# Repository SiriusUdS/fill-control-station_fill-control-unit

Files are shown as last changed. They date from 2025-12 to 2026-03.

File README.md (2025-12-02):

# template
Template repository. Repository name format: &lt;stm[model]|py|desktop>-&lt;project_name>-&lt;layer>  

Example:
- stmf411-engine-hal
- stm-engine-components

For the README.md file, it should be structured like the following:

---

# Project Name

> One-sentence summary describing what your project does or solves.

---

## Table of Contents
- [About](#about)
- [Project Structure](#project-structure)
- [Requirements](#requirements)
- [Installation / Build](#installation--build)
- [Usage](#usage)
- [Configuration](#configuration)
- [Troubleshooting](#troubleshooting)

---

## About

Explain what the project is, what problem it solves, and any relevant context.

Example:  
> This project implements the HAL layer of the engine project on the STMF411...

---

## Project Structure
project-root/  
│  
├── src/ # Source files  
├── include/ # Header files  
├── scripts/ # Utility scripts or build helpers  
├── config/ # Configuration or calibration files  
├── docs/ # Documentation and manuals  
├── tests/ # Unit or integration tests  
└── README.md  

---

## Requirements

List any hardware, software, or library dependencies needed to build or run the project.

Example:

- **Hardware:** STM32F4 Series, Raspberry Pi 4  
- **Compiler:** GCC 13+ or ARM-GCC toolchain  
- **Libraries:**  
  - HAL Drivers (for STM32)  
  - WiringPi (for Raspberry Pi)  
  - CMake ≥ 3.20  

---

## Installation / Build

List of steps required to install and build the project.

Example:

- Clone the project
- Download Visual Studio 2022 from this [Link](#www.duckduckgo.com)
- Open the sln file with Visual Studio
- Run the build

## Usage

List of steps required to run and/or debug the project.

Example:
- Open the project with Visual Studio 2022
- Press the `start` button

## Configuration

List of configuration files if any

Example:
- vcpkg.json
- .clang-tidy
- .clang-format

## Troubleshooting

QA kind of section with the most common problems and how to fix them

> The application build fails after the installation

Make sure that the vcpkg modules have been downloaded. Check the `use manifest` option in Visual Studio to see if the modules are downloaded automatically or not

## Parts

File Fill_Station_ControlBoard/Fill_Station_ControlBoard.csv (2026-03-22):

Id | Designator | Footprint | Quantity | Designation | Supplier and ref
1 | C52,C49,C13,C85,C60,C58,C56,C15,C6,C87,C69,C32,C101,C74,C65,C2,C100 | C_0603_1608Metric | 17 | 10u
2 | R12,R98,R97,R94,R43,R96,R95,R45,R46,R48,R44,R47,R4,R134,R132,R8,R9,R133 | R_0402_1005Metric | 18 | 10k
3 | Q3,Q2,Q1 | SOT-23 | 3 | AO3400A
4 | C78,C61,C75 | C_0603_1608Metric | 3 | 22u
5 | C71,C55,C5 | C_0805_2012Metric | 3 | 10u
6 | C4,C3,C84 | C_1210_3225Metric | 3 | 22u
7 | C59 | CP_Elec_5x5.3 | 1 | 10uF_50V
8 | C57 | CP_Elec_6.3x7.7 | 1 | 100uF_50V
9 | D15 | D_SOD-123 | 1 | 6.4V
10 | F2 | Fuse_1206_3216Metric | 1 | Polyfuse
11 | R68,R78,R67 | R_0603_1608Metric | 3 | R_US
12 | R99,R91,R38,R113,R101,R104,R100,R40,R39,R88,R116,R115,R41,R42,R89,R103,R114,R62,R92,R90,R93 | R_0402_1005Metric | 21 | 22
13 | J2 | TerminalBlock_Phoenix_PT-1,5-2-5.0-H_1x02_P5.00mm_Horizontal | 1 | Ematch1
14 | C116,C86,C117,C115,C14,C38,C63,C20,C1,C12 | C_0603_1608Metric | 10 | 100n
15 | D9,D12,D4,D7,D11,D8,D13,D14,D5,D10 | LED_0603_1608Metric | 10 | LED
16 | R32,R81,R30,R82,R29 | C_0603_1608Metric | 5 | 22
17 | C30,C41,C36,C48,C40,C37,C92,C28,C42,C94,C23,C25,C27,C31,C44,C91,C35,C46,C34,C39,C103,C90,C43,C33,C83,C16,C26,C98,C29 | C_0402_1005Metric | 29 | 100n
18 | R11,R77,R10 | R_0603_1608Metric | 3 | 1k
19 | C93,C105,C7,C89 | C_1210_3225Metric | 4 | 1000p - 2000V
20 | C73,C70 | C_0603_1608Metric | 2 | 100nF
21 | J19 | AMASS_XT60-M_1x02_P7.20mm_Vertical | 1 | ~
22 | J15 | USB_C_Receptacle_GCT_USB4105-xx-A_16P_TopMnt_Horizontal | 1 | USB_C_Receptacle_USB2.0_14P
23 | Y2 | Oscillator_SMD_Abracon_ASV-4Pin_7.0x5.1mm | 1 | ASV-32.768kHz
24 | C81,C72,C80,C107,C50,C62,C68,C22,C77,C45,C79,C9,C8,C47,C76,C112,C102,C97,C53 | C_0603_1608Metric | 19 | 1u
25 | C66 | C_0603_1608Metric | 1 | 10n
26 | R53,R52,R111 | C_0402_1005Metric | 3 | 10k
27 | R56,R55,R73,R86 | R_0603_1608Metric_Pad0.98x0.95mm_HandSolder | 4 | 0
28 | R34,R25 | R_0603_1608Metric_Pad0.98x0.95mm_HandSolder | 2 | 22
29 | D16 | D_SMA | 1 | SMAJ20A
30 | C95 | C_0402_1005Metric | 1 | 10u
31 | R3,R162,R2 | R_0603_1608Metric | 3 | 50m
32 | R50,R49,R28,R51,R35,R84,R26,R37,R117,R1,R87,R120,R119,R118 | R_0603_1608Metric_Pad0.98x0.95mm_HandSolder | 14 | 10k
33 | C11,C10 | CP_Elec_4x5.4 | 2 | 47uF
34 | R79,R80 | R_0603_1608Metric_Pad0.98x0.95mm_HandSolder | 2 | 5.1k
35 | R72,R71,R76,R33,R74,R31 | R_0603_1608Metric_Pad0.98x0.95mm_HandSolder | 6 | 680
36 | R65,R5 | C_0603_1608Metric | 2 | 365k
37 | R7,R75 | C_0603_1608Metric | 2 | 10k
38 | H2,H3,H4,H1 | MountingHole_3.2mm_With_Spacer_H10mm | 4 | M3_Hole_With_Spacer_H10mm
39 | C104,C99 | C_0402_1005Metric | 2 | 10n
40 | U10,U11,U12 | RDN0011A-MFG | 3 | TPSM33620-Q1
41 | J1 | RJ45_Wuerth_74980111211_Horizontal | 1 | RJ45_Wuerth_74980111211
42 | R54,R112 | C_0402_1005Metric | 2 | 0
43 | L4 | C_0402_1005Metric | 1 | L_Ferrite
44 | R64,R69,R70 | R_0603_1608Metric_Pad0.98x0.95mm_HandSolder | 3 | 1.5k
45 | J16 | DSUB-9_Socket_Vertical_P2.77x2.84mm_MountingHoles | 1 | DE9_Socket_MountingHoles
46 | Y1,Y4 | Oscillator_SMD_Abracon_ASV-4Pin_7.0x5.1mm | 2 | ASV-25.000MHz
47 | U2 | LQFP-176_24x24mm_P0.5mm | 1 | STM32H747IITx
48 | J12 | PinSocket_2x05_P2.00mm_Vertical | 1 | Conn_02x05_Counter_Clockwise
49 | J7,J8,J11 | TerminalBlock_Phoenix_PT-1,5-2-5.0-H_1x02_P5.00mm_Horizontal | 3 | Screw_Terminal_2_P5.00mm
50 | D1,D2,D3 | SOT-23 | 3 | BAV99
51 | BZ1 | Buzzer_Murata_PKMCS0909E | 1 | Buzzer_TDK_PS1240
52 | IC1 | WSON-8-1EP_2x2mm_P0.5mm_EP0.9x1.6mm_ThermalVias | 1 | TPS259573DSGR
53 | U9,U6 | SOT-583-8 | 2 | TPS2116DRL
54 | U1 | Texas_RGV0016A_VQFN-16-1EP_4x4mm_P0.65mm_EP2.1x2.1mm | 1 | INA3221
55 | J14,J10 | microSD_HC_Hirose_DM3AT-SF-PEJM5 | 2 | Micro_SD_Card_Det_Hirose_DM3AT
56 | C51,C96 | C_0402_1005Metric | 2 | *
57 | R27,R36 | R_0603_1608Metric_Pad0.98x0.95mm_HandSolder | 2 | 50k
58 | R66 | C_0603_1608Metric | 1 | 100k
59 | L2 | R_0402_1005Metric | 1 | L_Ferrite
60 | SW2 | SW_DPDT_CK_JS202011JCQN | 1 | BOOT
61 | U8 | SOIC-20W_7.5x12.8mm_P1.27mm | 1 | ISOW1044
62 | R107 | R_0603_1608Metric_Pad0.98x0.95mm_HandSolder | 1 | 270
63 | R6 | R_0603_1608Metric | 1 | 100k
64 | C88 | C_0603_1608Metric | 1 | 100u
65 | F1 | Fuse_0603_1608Metric | 1 | 4A
66 | J9 | TerminalBlock_Phoenix_PT-1,5-6-3.5-H_1x06_P3.50mm_Horizontal | 1 | Screw_Terminal_6_P3.50mm
67 | J6 | TerminalBlock_Phoenix_PT-1,5-2-5.0-H_1x02_P5.00mm_Horizontal | 1 | Ematch2
68 | R63 | C_0603_1608Metric | 1 | 4.7k
69 | BT1 | Battery_Panasonic_CR2032-HFN_Horizontal_CircularHoles | 1 | RTC_BAT
70 | SW1 | SW_DPDT_CK_JS202011JCQN | 1 | RESET
71 | R106 | R_0603_1608Metric_Pad0.98x0.95mm_HandSolder | 1 | 1M
72 | U7 | SOT-23-6 | 1 | USBLC6-2SC6
73 | C67 | C_0603_1608Metric | 1 | 10nF
74 | C64 | C_0603_1608Metric | 1 | 3.3n
75 | U5 | Texas_RMQ0024A_WQFN-24-1EP_3x3mm_P0.4mm_EP1.9x1.9mm | 1 | DP83825I
76 | CR2 | SOT323-3L_STM | 1 | ESDCAN02-2BWY
77 | C54,C24 | C_0603_1608Metric | 2 | 4.7u
78 | C18,C19,C17,C21 | C_0603_1608Metric | 4 | 2.2u
79 | R85 | R_0603_1608Metric_Pad0.98x0.95mm_HandSolder | 1 | 120
80 | TP3,TP1,TP2,TP4 | TestPoint_Pad_D2.0mm | 4 | TestPoint
81 | J17,J18 | PinHeader_1x06_P2.54mm_Vertical | 2 | PINHD_1x6_Male
82 | R102 | R_0402_1005Metric | 1 | 6.49k

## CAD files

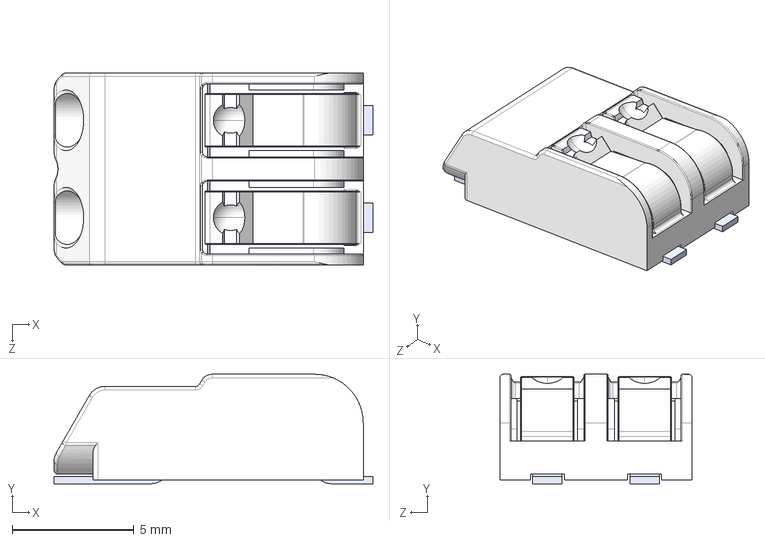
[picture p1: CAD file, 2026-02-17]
Fill_Station_ControlBoard/Librairies/3D/2060-452_998-404.STEP
13.1 x 4.50 x 7.90 mm

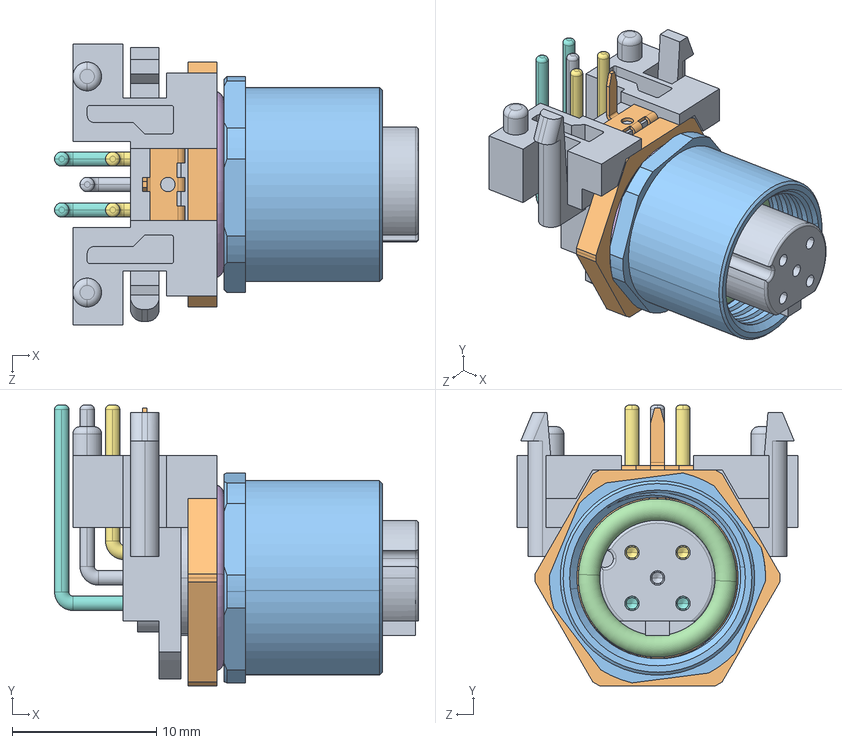
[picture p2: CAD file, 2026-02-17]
Fill_Station_ControlBoard/Librairies/3D/54-00386.STEP
25.3 x 19.5 x 19.5 mm

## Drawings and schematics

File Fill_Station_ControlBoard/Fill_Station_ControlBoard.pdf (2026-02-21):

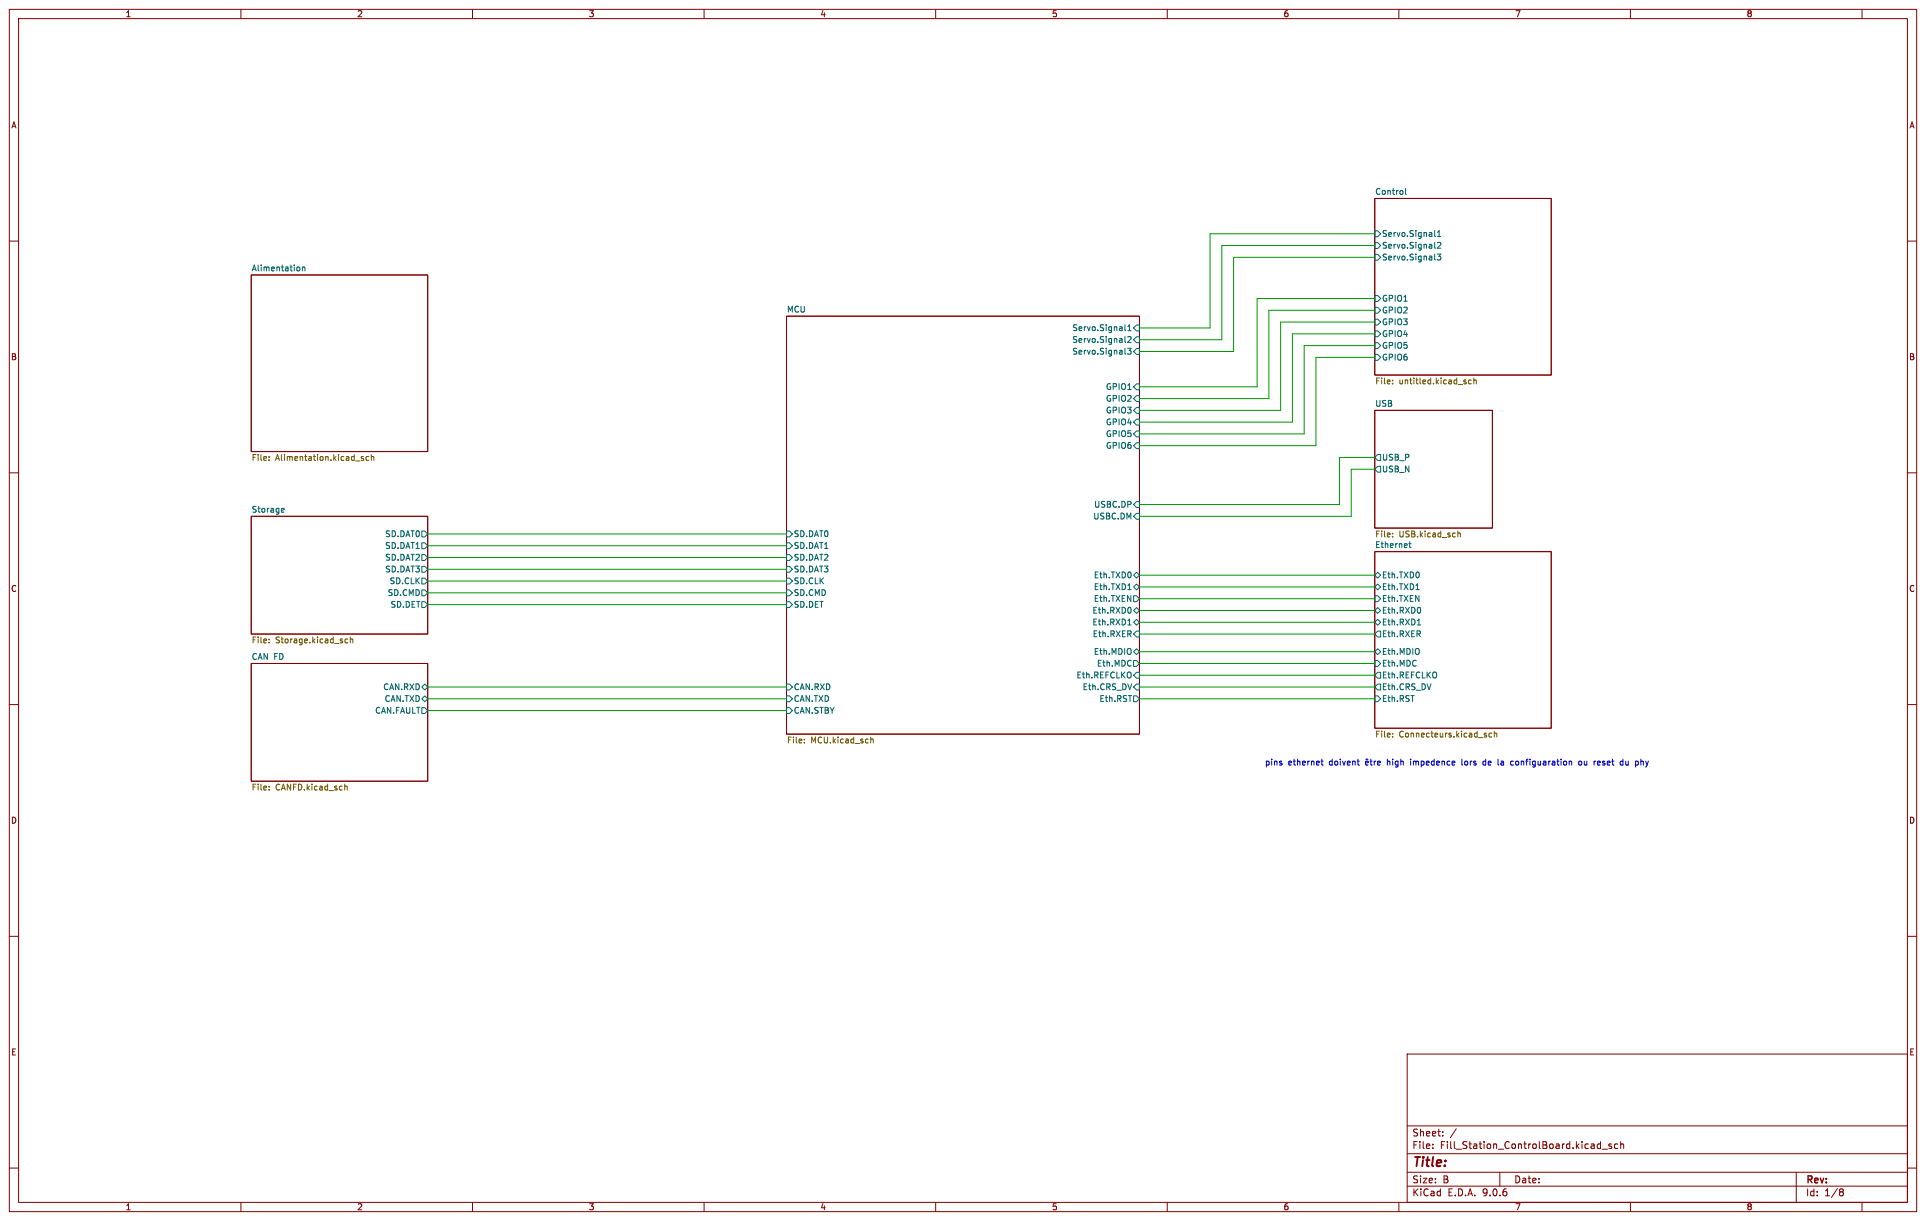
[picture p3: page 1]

Servo.Signal3 GPIO1 GPIO5 GPIO6 GPIO3 GPIO2 GPIO4 Control File: untitled.kicad_sch
File: USB.kicad_sch Servo.Signal1
Servo.Signal2

Servo.Signal1
Eth.TXD1 Eth.RXD1 Eth.RXD0 GPIO1 GPIO4 GPIO5 GPIO6 GPIO2 GPIO3 Servo.Signal2

USBC.DP CAN.TXD

SD.DAT2 SD.DAT0 SD.DAT1 SD.DAT3 SD.CLK

Eth.RST Eth.TXD0 Eth.MDIO

CAN.FAULT CAN FD

Eth.RST Eth.REFCLKO
Eth.CRS_DV

Id: 1/8 Title: File: Fill_Station_ControlBoard.kicad_sch Sheet: /

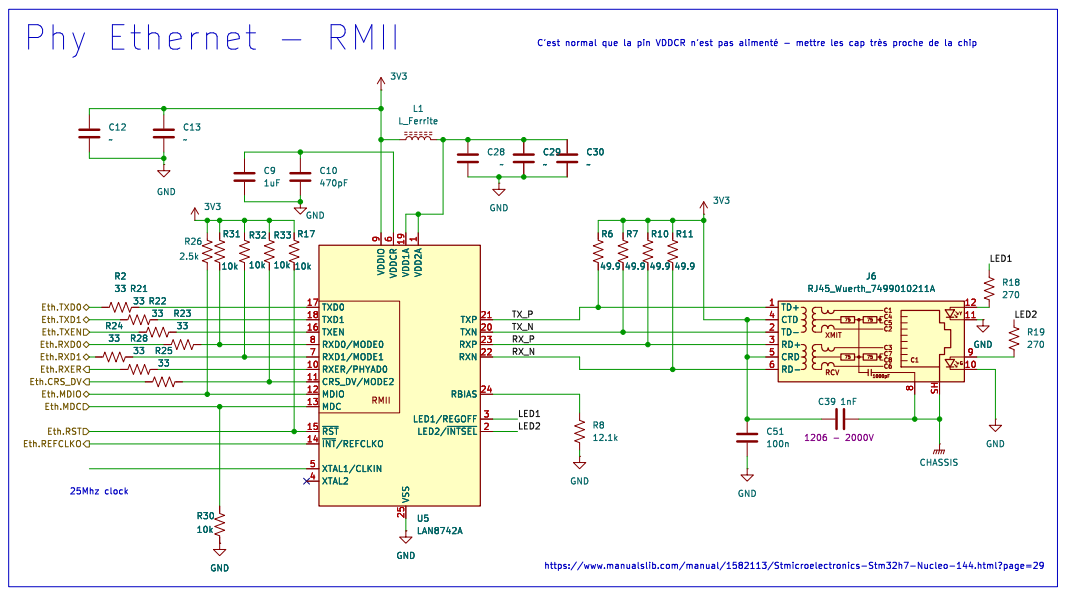
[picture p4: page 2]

1 TXP 21 TXN 20 RXP 23 RXN 22 RBIAS 24

Eth.TXD1 Eth.TXD0 Eth.RXD1 Eth.TXEN

Eth.CRS_DV
Eth.MDIO
Eth.RST Eth.MDC

Id: 2/8 Title: File: Connecteurs.kicad_sch Sheet: /Ethernet/

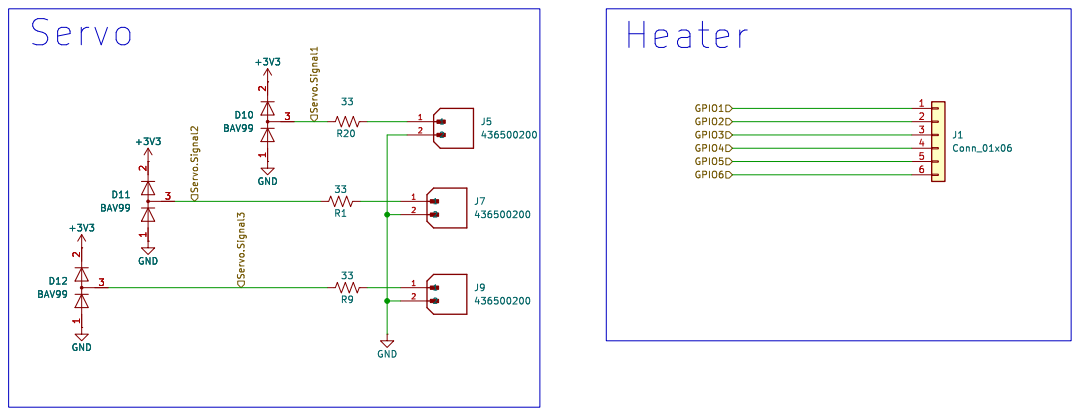
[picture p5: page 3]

Id: 3/8 Title: File: untitled.kicad_sch Sheet: /Control/ GND

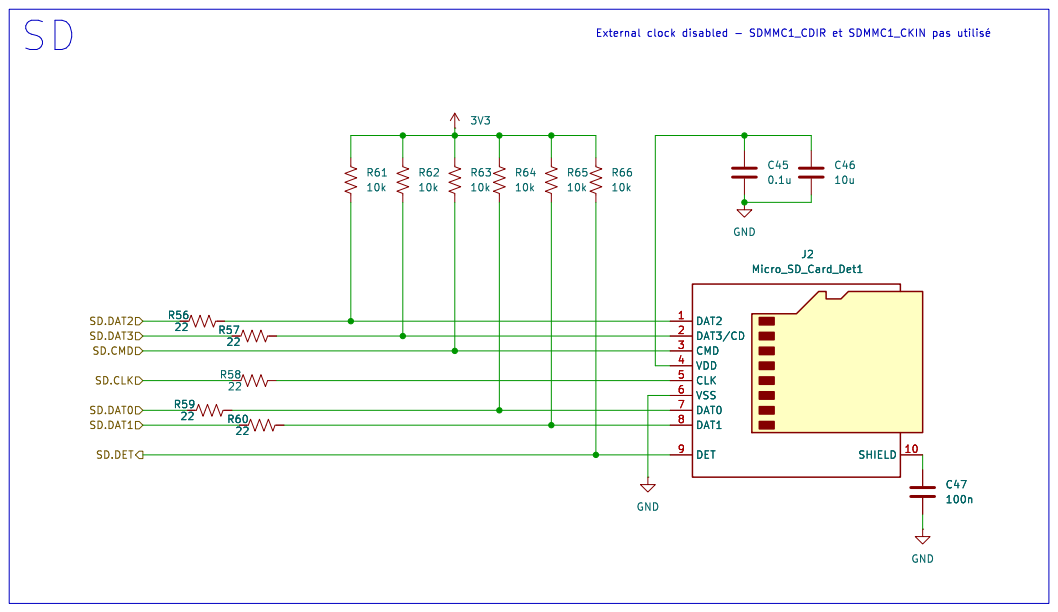
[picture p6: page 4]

0.1u SD.DET SD.CLK

SD.DAT0 SD.DAT1 SD.CMD

Id: 4/8 Title: File: Storage.kicad_sch Sheet: /Storage/

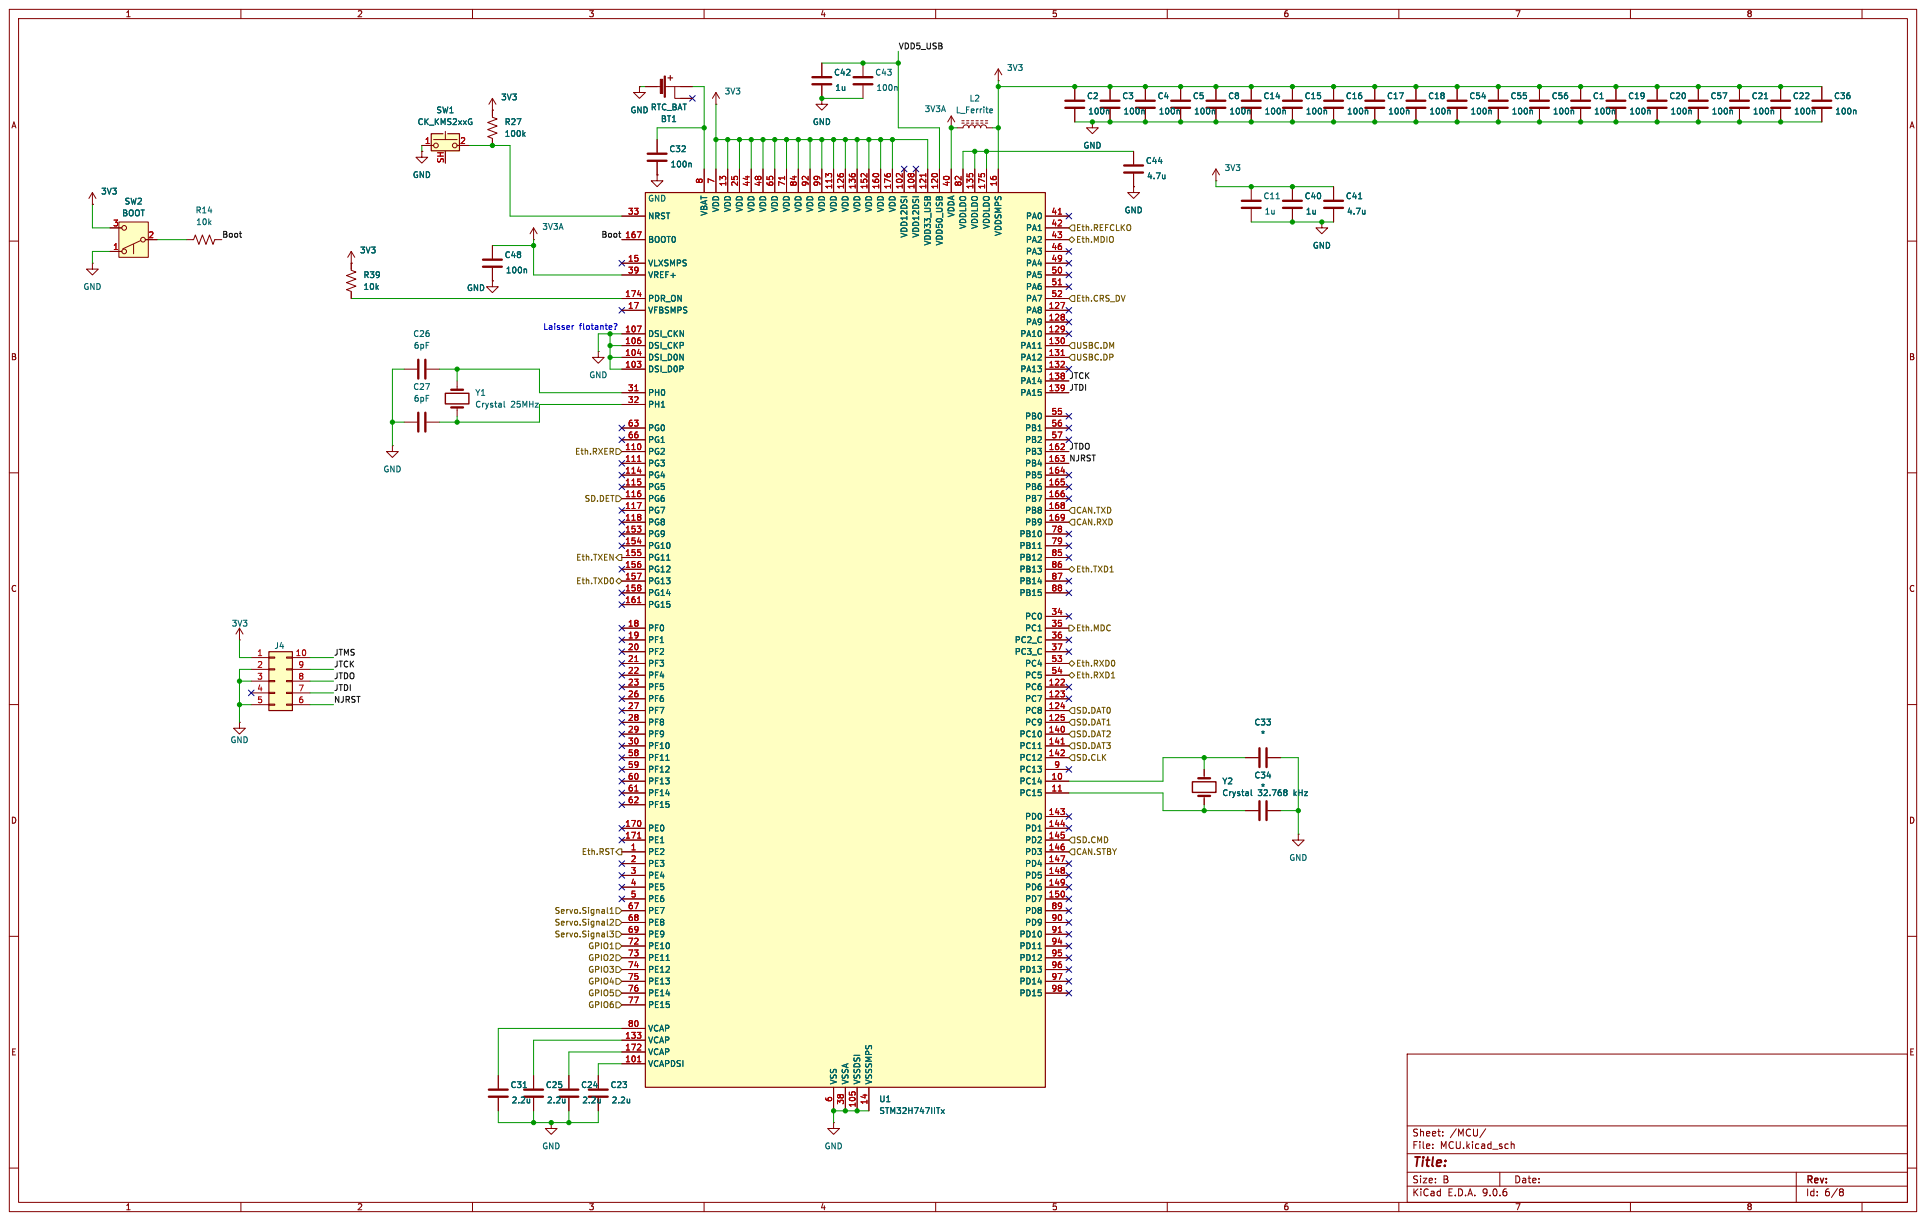
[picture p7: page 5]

SD.DAT3 SD.DAT0 SD.CLK

Id: 6/8 Title: File: MCU.kicad_sch Sheet: /MCU/

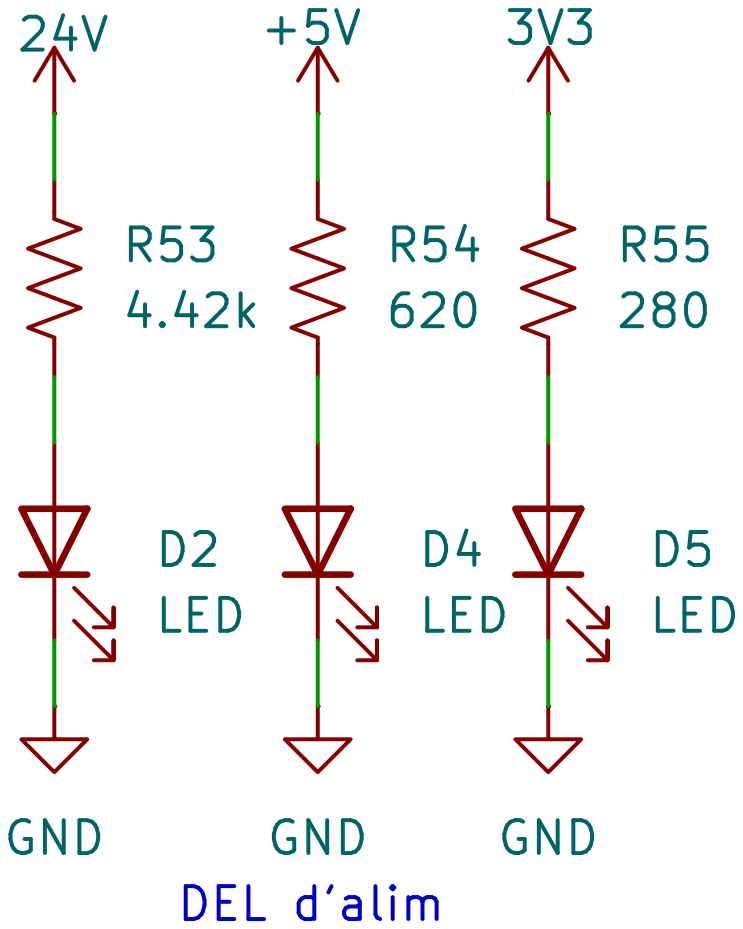
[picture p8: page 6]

Id: 7/8 Title: File: Alimentation.kicad_sch Sheet: /Alimentation/

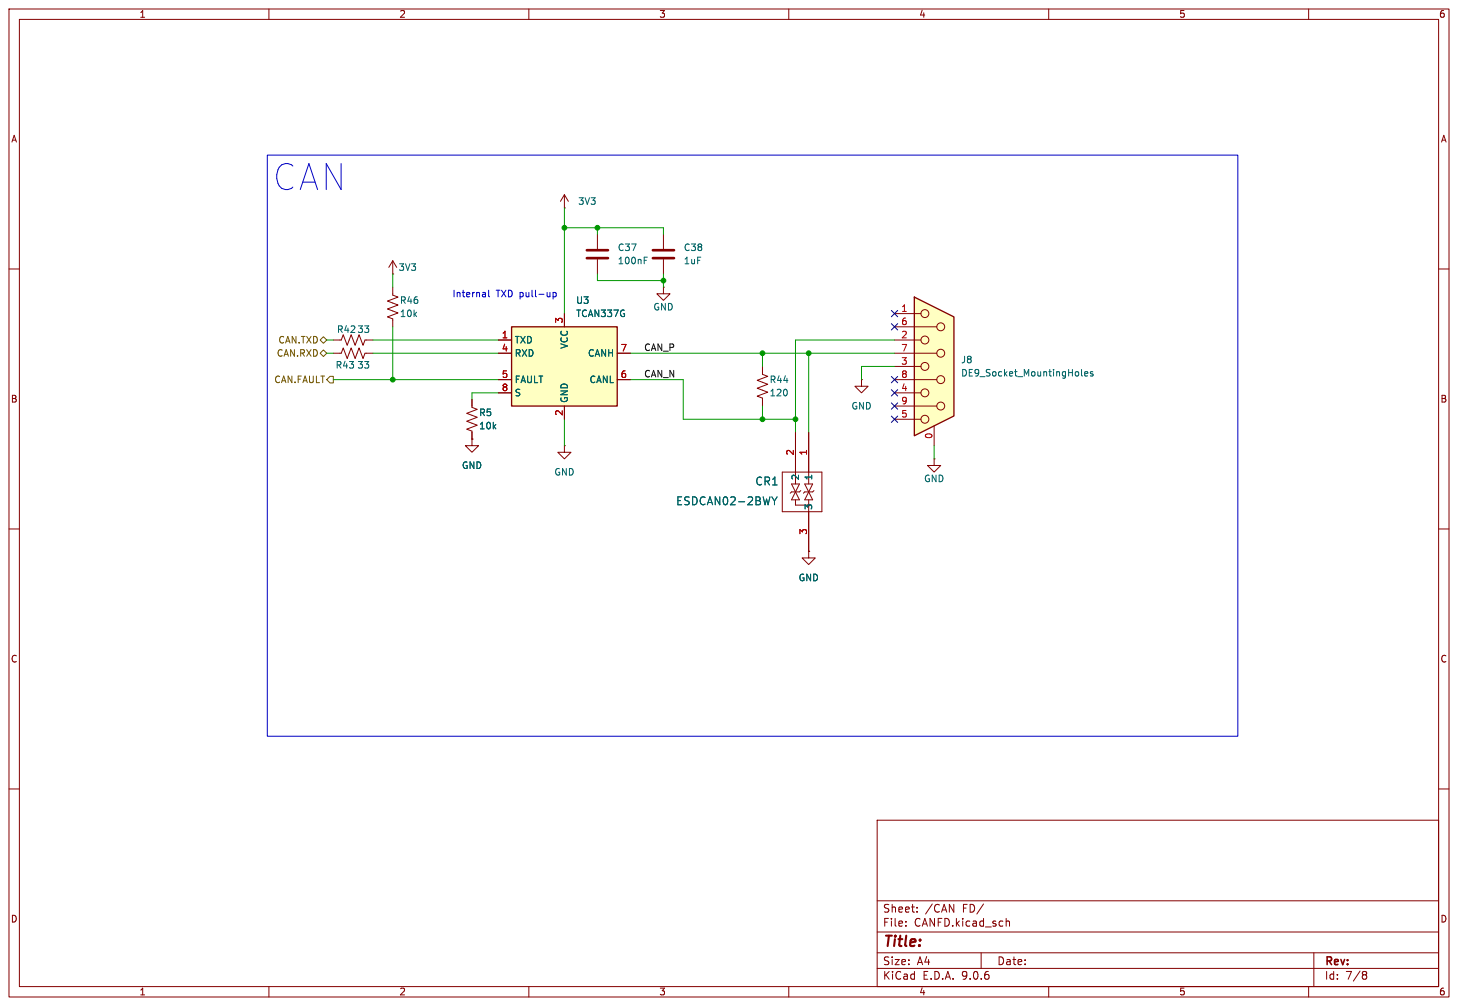
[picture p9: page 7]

2 CANH 7 CANL 6 U3 TCAN337G GND GND

CAN.FAULT CAN.TXD

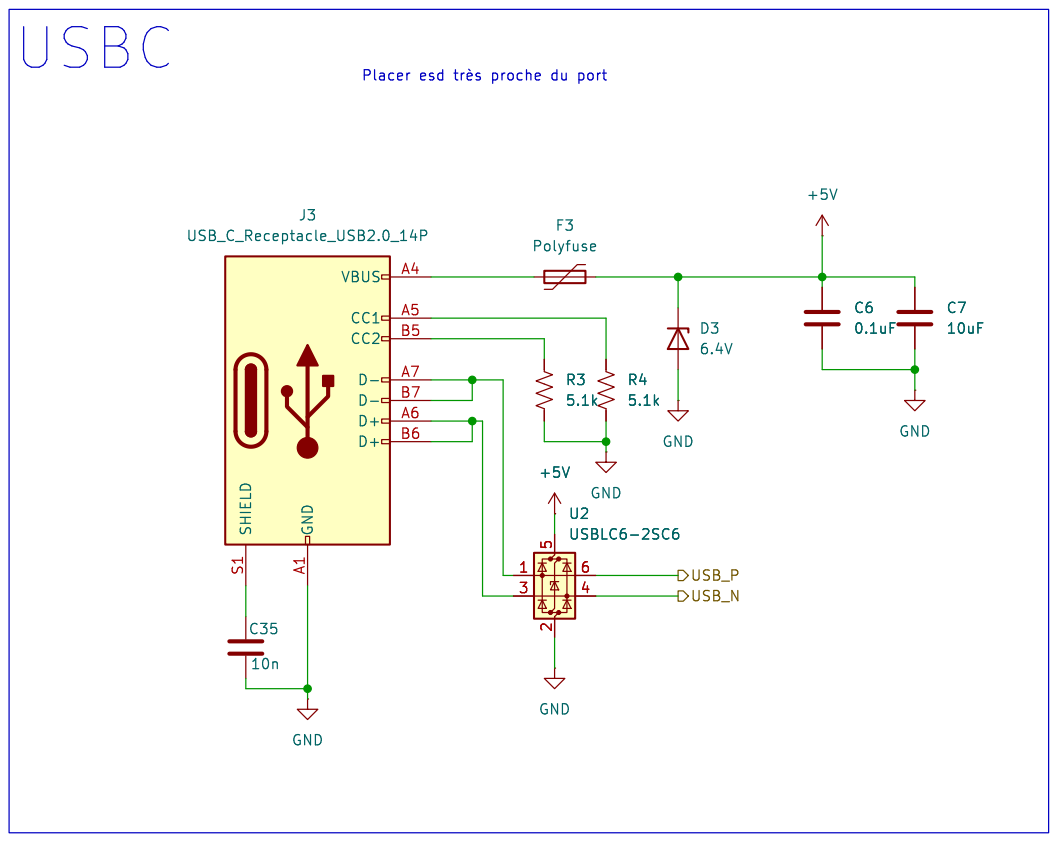
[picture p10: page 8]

Id: 8/8 Title: File: USB.kicad_sch Sheet: /USB/ C35

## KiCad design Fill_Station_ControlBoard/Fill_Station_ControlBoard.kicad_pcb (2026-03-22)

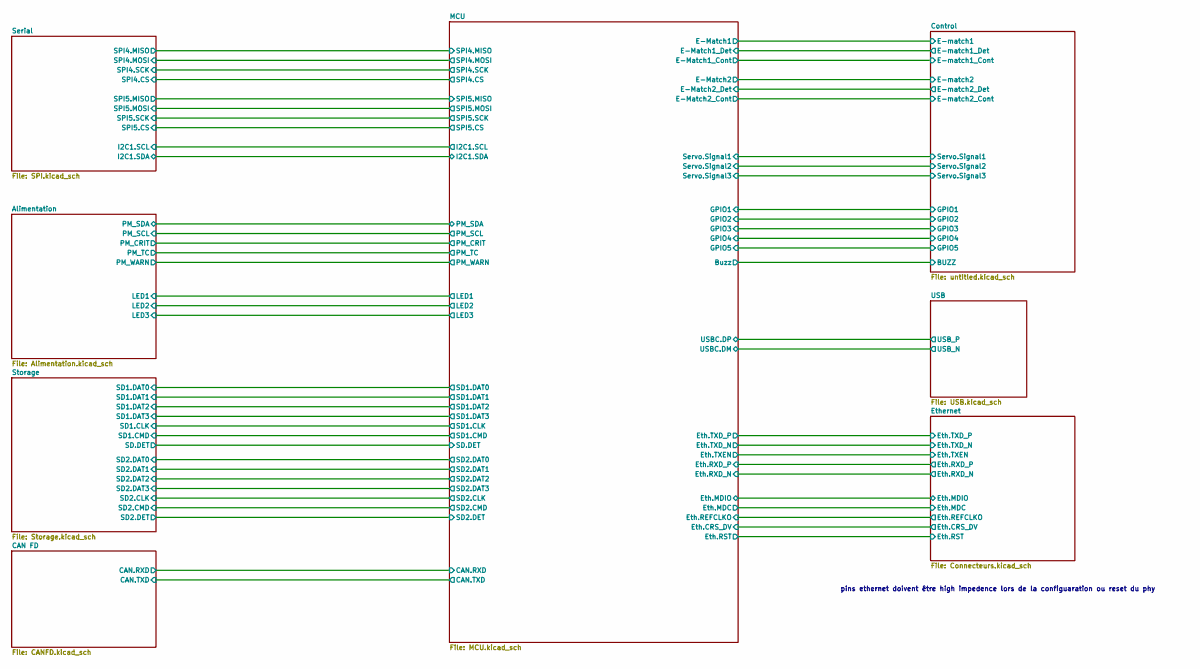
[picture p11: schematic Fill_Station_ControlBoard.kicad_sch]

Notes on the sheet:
pins ethernet doivent être high impedence lors de la configuaration ou reset du phy

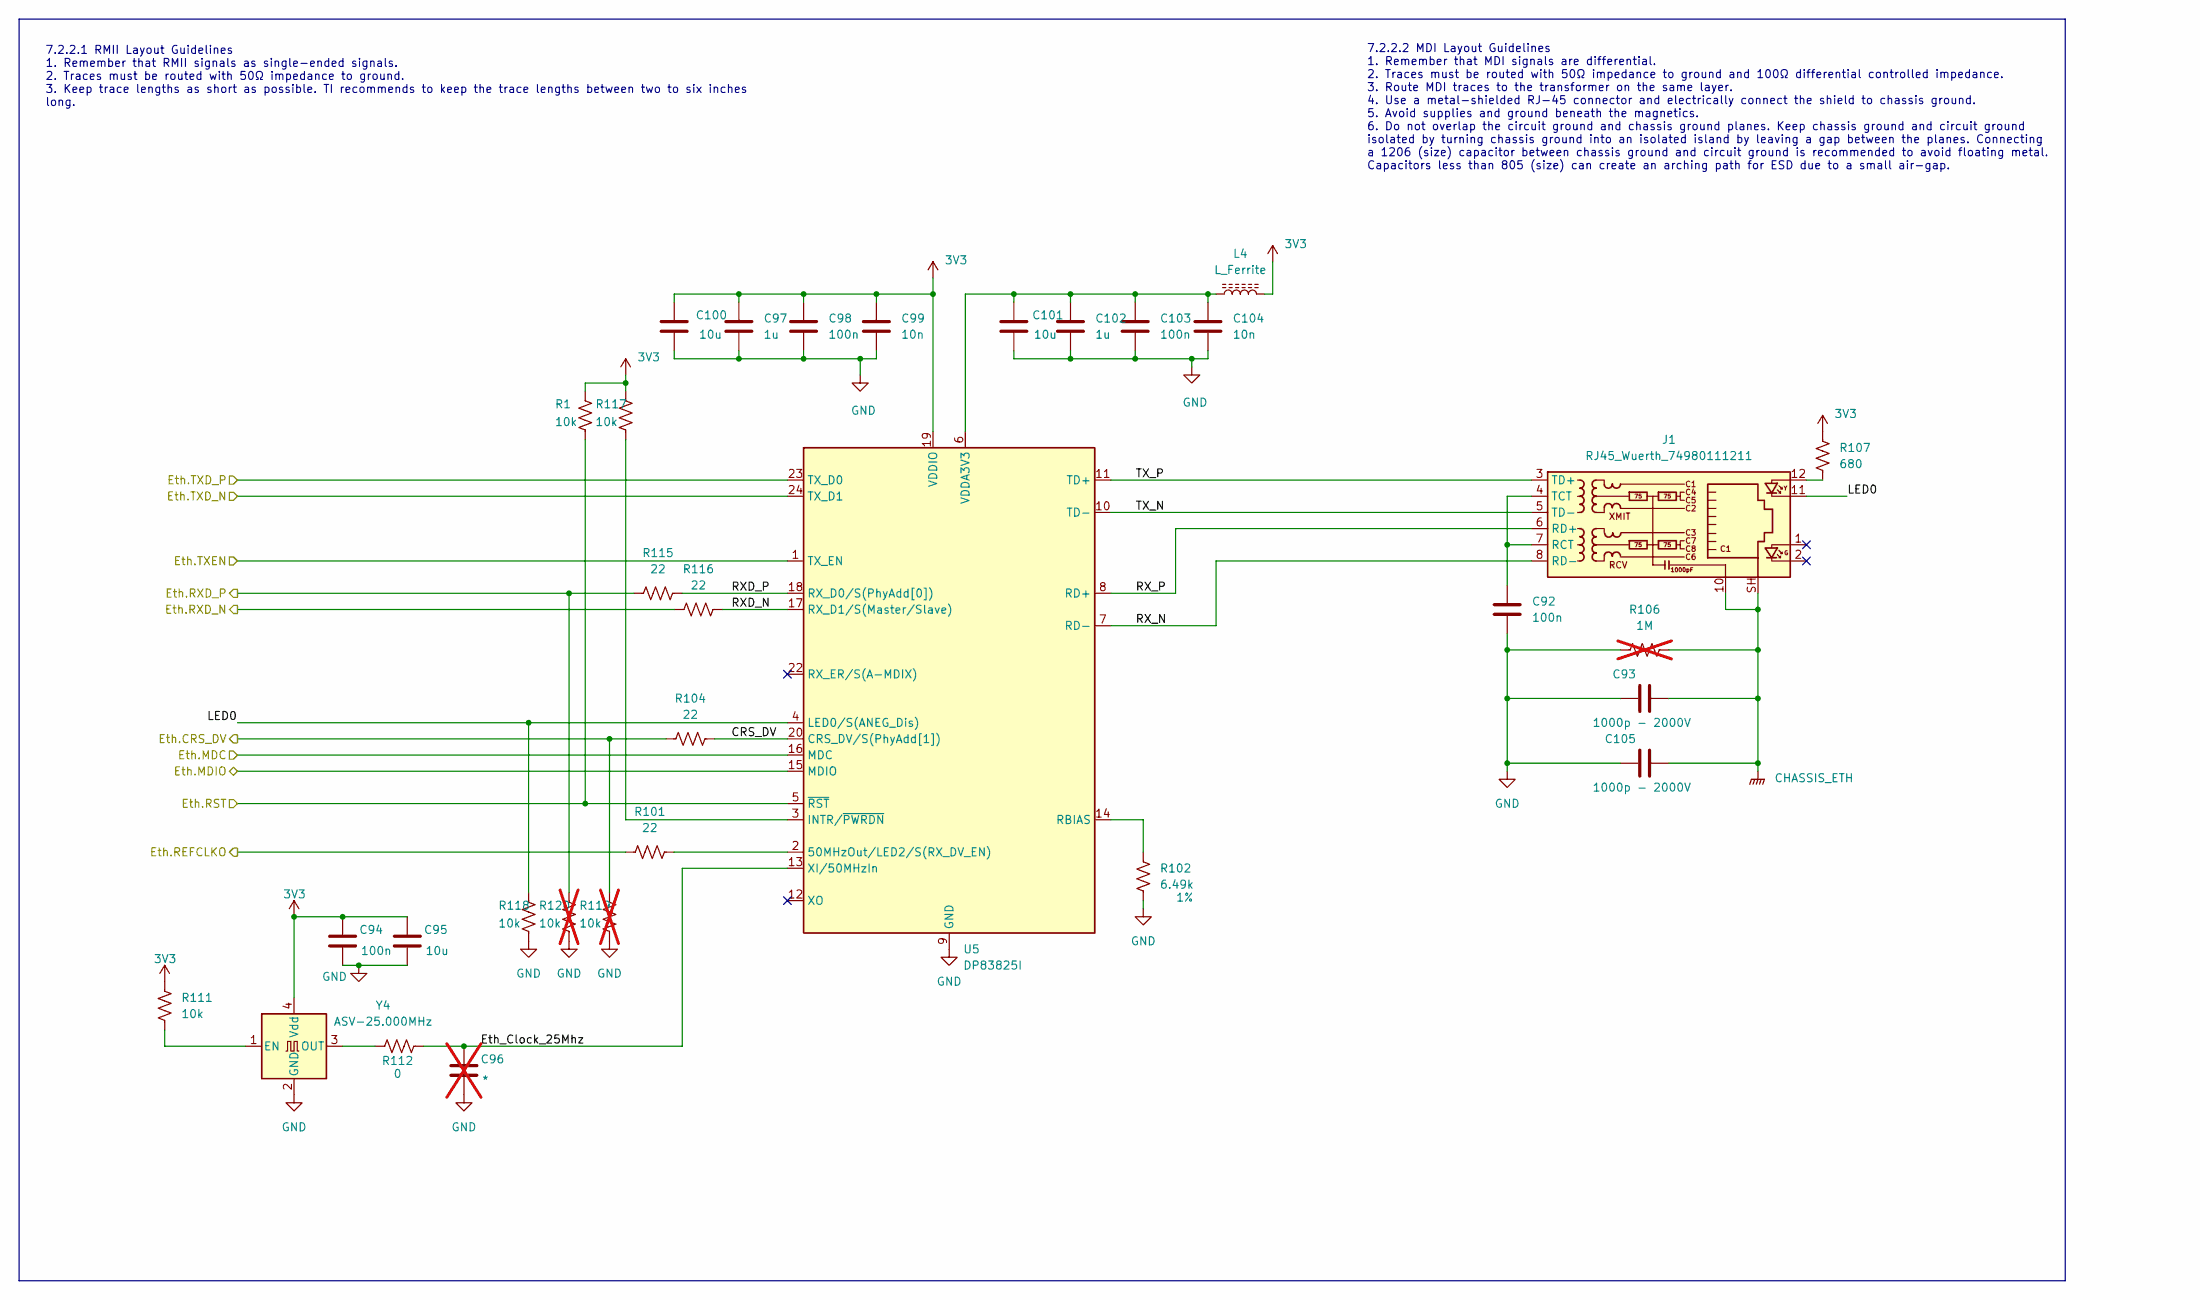
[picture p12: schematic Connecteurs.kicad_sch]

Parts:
C92, C94, C98, C103: 100n; C_0402_1005Metric; LCSC C60474
C93, C105: 1000p - 2000V; C_1210_3225Metric; LCSC C9196
C95, C100, C101: 10u; C_0603_1608Metric; LCSC C22399626
C96: *; C_0402_1005Metric; not fitted
C97, C102: 1u; C_0603_1608Metric; LCSC C59302
C99, C104: 10n; C_0402_1005Metric; LCSC C3850633
J1: RJ45_Wuerth_74980111211; RJ45_Wuerth_74980111211_Horizontal; LCSC C5523973
L4: L_Ferrite; R_0402_1005Metric; LCSC C160977
R1, R117, R118: 10k; R_0603_1608Metric; LCSC C22369937
R101, R104, R115, R116: 22; R_0402_1005Metric; LCSC C25092
R102: 6.49k; R_0402_1005Metric; LCSC C25916
R106: 1M; R_0603_1608Metric_Pad0.98x0.95mm_HandSolder; not fitted
R107: 680; R_0603_1608Metric_Pad0.98x0.95mm_HandSolder; LCSC C22356475
R111: 10k; R_0402_1005Metric; LCSC C173683
R112: 0; R_0402_1005Metric; LCSC C17168
R119, R120: 10k; R_0603_1608Metric; not fitted
U5: DP83825I; Texas_RMQ0024A_WQFN-24-1EP_3x3mm_P0.4mm_EP1.9x1.9mm; LCSC C783599
Y4: ASV-25.000MHz; Oscillator_SMD_Abracon_ASV-4Pin_7.0x5.1mm; LCSC C1987509

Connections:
3V3: C94.1, C95.1, C97.1, C98.1, C99.1, C100.1, L4.2, R1.1, R107.1, R111.1, R117.1, U5.19 (VDDIO), Y4.4 (Vdd); also elsewhere on the board
/Ethernet/CRS_DV: R104.2, U5.20 (CRS_DV/S(PhyAdd[1]))
/Ethernet/Eth.CRS_DV: R104.1, R119.1; also elsewhere on the board
/Ethernet/Eth.MDC: U5.16 (MDC); also elsewhere on the board
/Ethernet/Eth.MDIO: U5.15 (MDIO); also elsewhere on the board
/Ethernet/Eth.REFCLKO: R101.1; also elsewhere on the board
/Ethernet/Eth.RST: R1.2, U5.5 (~RST); also elsewhere on the board
/Ethernet/Eth.RXD_N: R116.1; also elsewhere on the board
/Ethernet/Eth.RXD_P: R115.1, R120.1; also elsewhere on the board
/Ethernet/Eth.TXD_N: U5.24 (TX_D1); also elsewhere on the board
/Ethernet/Eth.TXD_P: U5.23 (TX_D0); also elsewhere on the board
/Ethernet/Eth.TXEN: U5.1 (TX_EN); also elsewhere on the board
/Ethernet/Eth_Clock_25Mhz: C96.1, R112.2, U5.13 (XI/50MHzIn)
/Ethernet/LED0: J1.11, R118.1, U5.4 (LED0/S(ANEG_Dis))
/Ethernet/RXD_N: R116.2, U5.17 (RX_D1/S(Master/Slave))
/Ethernet/RXD_P: R115.2, U5.18 (RX_D0/S(PhyAdd[0]))
/Ethernet/RX_N: J1.8 (RD-), U5.7 (RD-)
/Ethernet/RX_P: J1.6 (RD+), U5.8 (RD+)
/Ethernet/TX_N: J1.5 (TD-), U5.10 (TD-)
/Ethernet/TX_P: J1.3 (TD+), U5.11 (TD+)
CHASSIS_ETH: C93.2, C105.2, J1.10, J1.SH, R106.2
GND: C92.2, C93.1, C94.2, C95.2, C96.2, C97.2, C98.2, C99.2, C100.2, C101.2, C102.2, C103.2, C104.2, C105.1, R102.2, R106.1, R118.2, R119.2, R120.2, U5.9 (GND), U5.21 (GND), U5.25 (GND), Y4.2 (GND); also elsewhere on the board
unnamed: J1.12, R107.2
unnamed: C92.1, J1.4 (TCT), J1.7 (RCT)
unnamed: R101.2, U5.2 (50MHzOut/LED2/S(RX_DV_EN))
unnamed: R117.2, U5.3 (INTR/~PWRDN)
unnamed: R102.1, U5.14 (RBIAS)
unnamed: C101.1, C102.1, C103.1, C104.1, L4.1, U5.6 (VDDA3V3)
unnamed: R111.2, Y4.1 (EN)
unnamed: R112.1, Y4.3 (OUT)

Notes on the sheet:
7.2.2.1 RMII Layout Guidelines 1. Remember that RMII signals as single-ended signals. 2. Traces must be routed with 50Ω impedance to ground. 3. Keep trace lengths as short as possible. TI recommends to keep the trace lengths between two to six inches long.
7.2.2.2 MDI Layout Guidelines 1. Remember that MDI signals are differential. 2. Traces must be routed with 50Ω impedance to ground and 100Ω differential controlled impedance. 3. Route MDI traces to the transformer on the same layer. 4. Use a metal-shielded RJ-45 connector and electrically connect t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

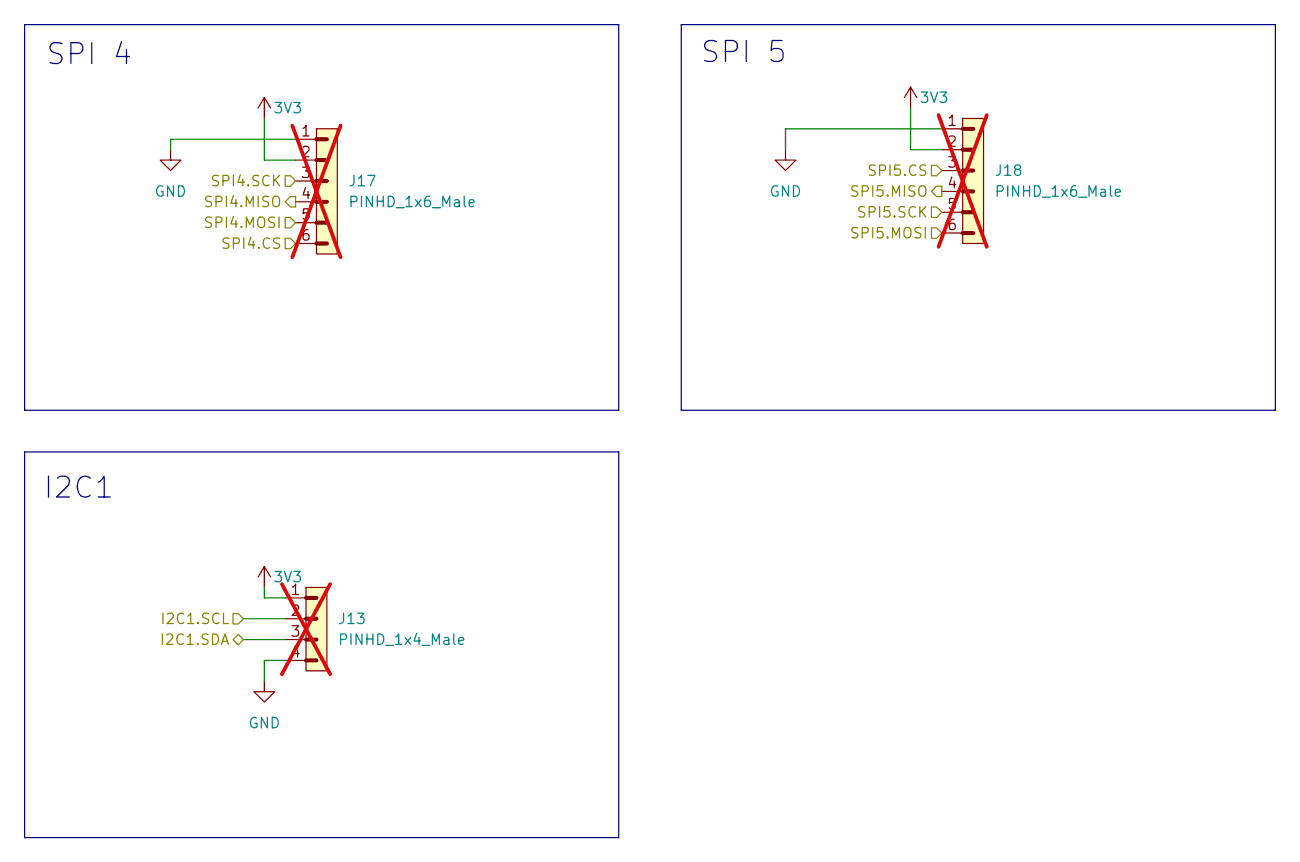
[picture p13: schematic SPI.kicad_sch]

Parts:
J13: PINHD_1x4_Male; PinHeader_1x04_P2.54mm_Vertical; not fitted
J17, J18: PINHD_1x6_Male; PinHeader_1x06_P2.54mm_Vertical; not fitted

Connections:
3V3: J13.1, J17.2, J18.2; also elsewhere on the board
/MCU/I2C1.SCL: J13.2; also elsewhere on the board
/MCU/I2C1.SDA: J13.3; also elsewhere on the board
/MCU/SPI4.CS: J17.6; also elsewhere on the board
/MCU/SPI4.MISO: J17.4; also elsewhere on the board
/MCU/SPI4.MOSI: J17.5; also elsewhere on the board
/MCU/SPI4.SCK: J17.3; also elsewhere on the board
/MCU/SPI5.CS: J18.3; also elsewhere on the board
/MCU/SPI5.MISO: J18.4; also elsewhere on the board
/MCU/SPI5.MOSI: J18.6; also elsewhere on the board
/MCU/SPI5.SCK: J18.5; also elsewhere on the board
GND: J13.4, J17.1, J18.1; also elsewhere on the board

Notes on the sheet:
SPI 5
SPI 4
I2C1

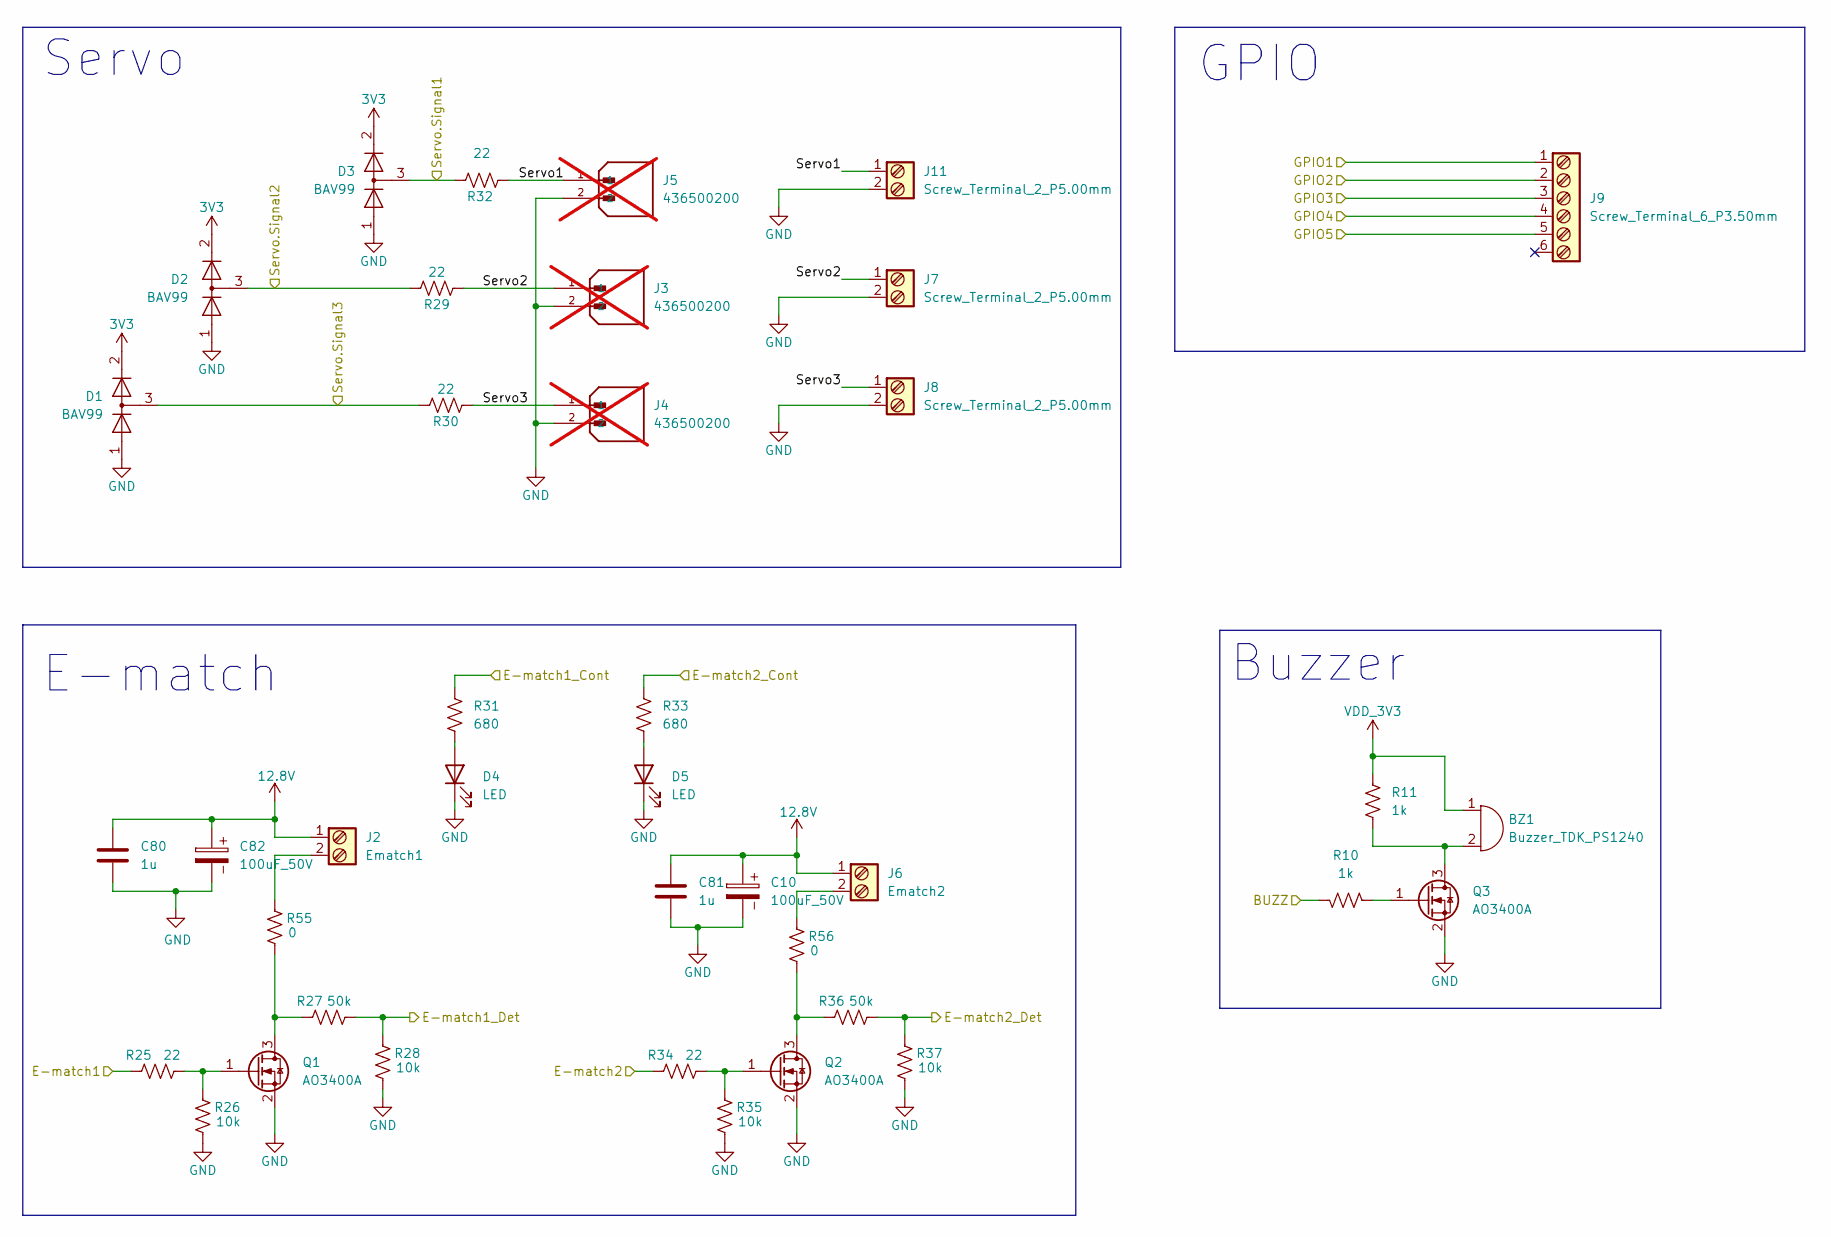
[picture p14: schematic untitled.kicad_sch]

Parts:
BZ1: Buzzer_TDK_PS1240; Buzzer_Murata_PKMCS0909E; Manufacturer Part Number PS1240P02BT; LCSC C910763
C10, C82: 100uF_50V; CP_Elec_6.3x7.7; LCSC C165974
C80, C81: 1u; C_0603_1608Metric; LCSC C59302
D1, D2, D3: BAV99; SOT-23; LCSC C68983
D4, D5: LED; LED_0603_1608Metric; LCSC C2286
J2: Ematch1; TerminalBlock_Phoenix_PT-1,5-2-5.0-H_1x02_P5.00mm_Horizontal
J3, J4, J5: 436500200; MOLEX_436500200; PARTREV D7; not fitted
J6: Ematch2; TerminalBlock_Phoenix_PT-1,5-2-5.0-H_1x02_P5.00mm_Horizontal
J7, J8, J11: Screw_Terminal_2_P5.00mm; TerminalBlock_Phoenix_PT-1,5-2-5.0-H_1x02_P5.00mm_Horizontal
J9: Screw_Terminal_6_P3.50mm; TerminalBlock_Phoenix_PT-1,5-6-3.5-H_1x06_P3.50mm_Horizontal
Q1, Q2, Q3: AO3400A; SOT-23; LCSC C20917
R10, R11: 1k; R_0603_1608Metric; LCSC C22356624
R25, R29, R30, R32, R34: 22; R_0402_1005Metric; LCSC C25092
R26, R28, R35, R37: 10k; R_0603_1608Metric; LCSC C22369937
R27, R36: 50k; R_0603_1608Metric_Pad0.98x0.95mm_HandSolder; LCSC C861451
R31, R33: 680; R_0603_1608Metric_Pad0.98x0.95mm_HandSolder; LCSC C22356475
R55, R56: 0; R_0402_1005Metric; LCSC C17168

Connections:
3V3: D1.2 (A), D2.2 (A), D3.2 (A); also elsewhere on the board
12.8V: C10.1, C80.1, C81.1, C82.1, J2.1, J6.1; also elsewhere on the board
/Control/BUZZ: R10.2; also elsewhere on the board
/Control/E-match1: R25.1; also elsewhere on the board
/Control/E-match1_Cont: R31.2; also elsewhere on the board
/Control/E-match1_Det: R27.2, R28.1; also elsewhere on the board
/Control/E-match2: R34.1; also elsewhere on the board
/Control/E-match2_Cont: R33.2; also elsewhere on the board
/Control/E-match2_Det: R36.2, R37.1; also elsewhere on the board
/Control/GPIO1: J9.1; also elsewhere on the board
/Control/GPIO2: J9.2; also elsewhere on the board
/Control/GPIO3: J9.3; also elsewhere on the board
/Control/GPIO4: J9.4; also elsewhere on the board
/Control/GPIO5: J9.5; also elsewhere on the board
/Control/Servo1: J5.1, J11.1, R32.2
/Control/Servo2: J3.1, J7.1, R29.1
/Control/Servo3: J4.1, J8.1, R30.1
/Control/Servo.Signal1: D3.3 (K), R32.1; also elsewhere on the board
/Control/Servo.Signal2: D2.3 (K), R29.2; also elsewhere on the board
/Control/Servo.Signal3: D1.3 (K), R30.2; also elsewhere on the board
GND: C10.2, C80.2, C81.2, C82.2, D1.1 (K), D2.1 (K), D3.1 (K), D4.1 (K), D5.1 (K), J3.2, J4.2, J5.2, J7.2, J8.2, J11.2, Q1.2 (S), Q2.2 (S), Q3.2 (S), R26.2, R28.2, R35.2, R37.2; also elsewhere on the board
unnamed: D4.2 (A), R31.1
unnamed: D5.2 (A), R33.1
unnamed: J2.2, R55.1
unnamed: J6.2, R56.1
unnamed: Q1.3 (D), R27.1, R55.2
unnamed: Q1.1 (G), R25.2, R26.1
unnamed: Q2.3 (D), R36.1, R56.2
unnamed: Q2.1 (G), R34.2, R35.1
unnamed: BZ1.2, Q3.3 (D), R11.2
unnamed: Q3.1 (G), R10.1
VDD_3V3: BZ1.1, R11.1

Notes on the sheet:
GPIO
E-match
Buzzer
Servo

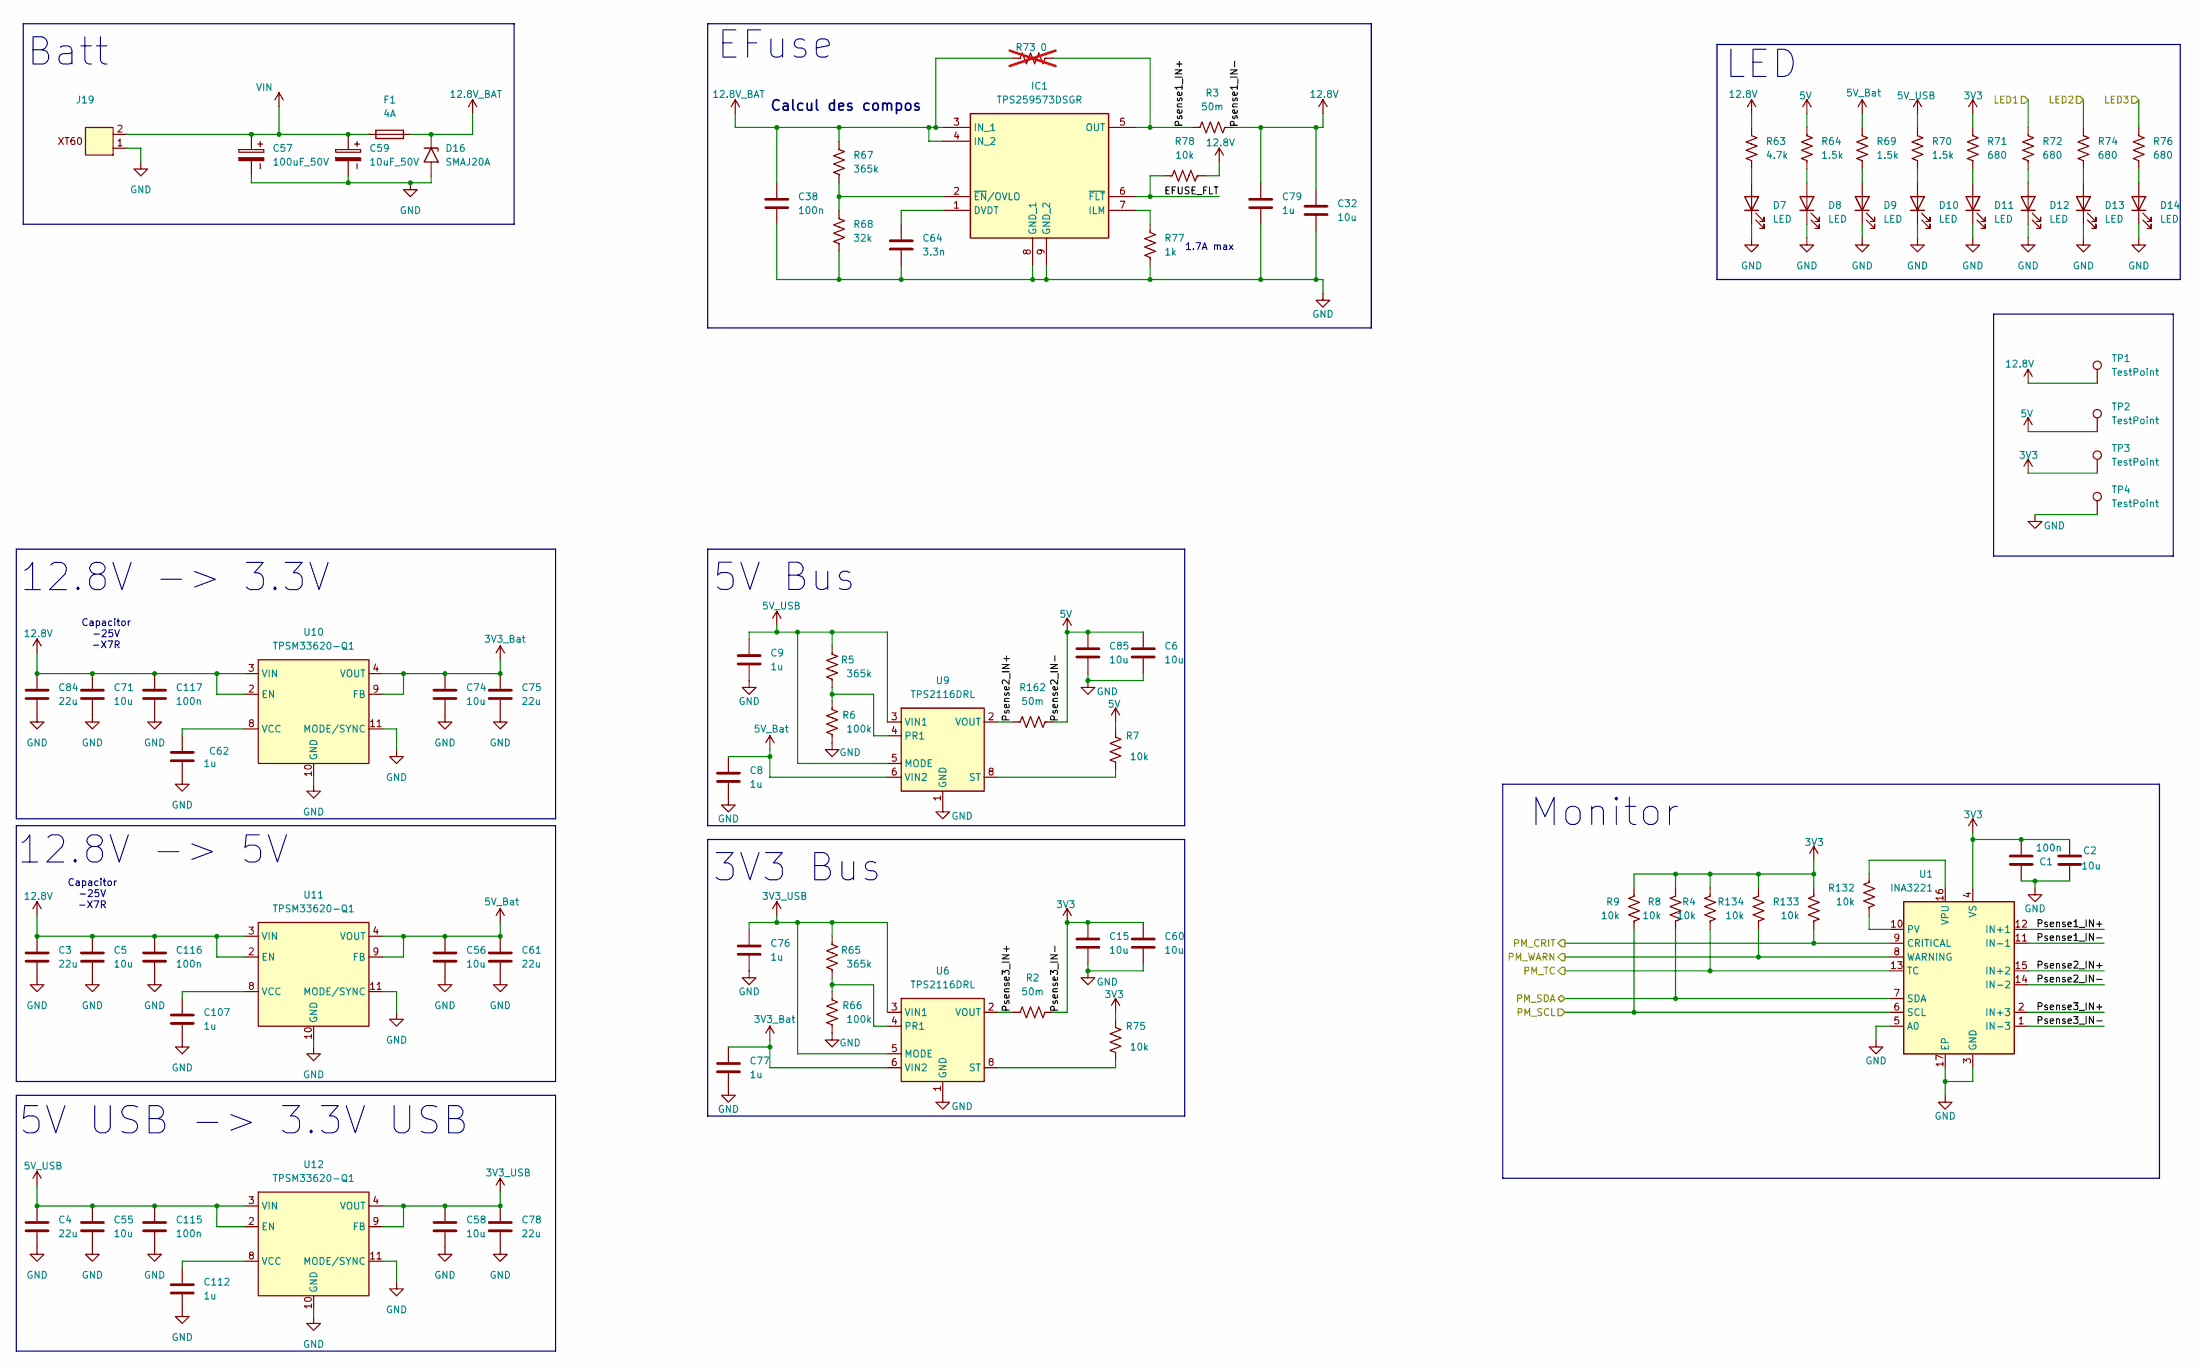
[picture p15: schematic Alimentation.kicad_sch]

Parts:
C1, C38, C115, C116, C117: 100n; C_0603_1608Metric; LCSC C14663
C2, C6, C15, C56, C58, C60, C74, C85: 10u; C_0603_1608Metric; LCSC C22399626
C3, C4: 22u; C_1210_3225Metric; LCSC C5341638
C5, C55, C71: 10u; C_0805_2012Metric; LCSC C326595
C8, C9, C62, C76, C77, C79, C107, C112: 1u; C_0603_1608Metric; LCSC C59302
C32: 10u; C_0603_1608Metric
C57: 100uF_50V; CP_Elec_6.3x7.7; LCSC C165974
C59: 10uF_50V; CP_Elec_5x5.3
C61, C75, C78: 22u; C_0603_1608Metric; LCSC C60077
C64: 3.3n; C_0603_1608Metric
C84: 22u; R_0603_1608Metric; LCSC C5341638
D7, D11, D12: LED; LED_0603_1608Metric; LCSC C12065
D8, D9, D10: LED; LED_0603_1608Metric; LCSC C2288
D13, D14: LED; LED_0603_1608Metric; LCSC C2286
D16: SMAJ20A; D_SMA; LCSC C10763
F1: 4A; Fuse_0603_1608Metric; LCSC C187606
IC1: TPS259573DSGR; WSON-8-1EP_2x2mm_P0.5mm_EP0.9x1.6mm_ThermalVias; Mouser Part Number 595-TPS259573DSGR
J19: AMASS_XT60-M_1x02_P7.20mm_Vertical; LCSC C98733
R2, R3, R162: 50m; R_0603_1608Metric; LCSC C2074926
R4, R8, R9, R132, R133, R134: 10k; R_0402_1005Metric; LCSC C173683
R5, R65, R67: 365k; R_0603_1608Metric
R6: 100k; R_0603_1608Metric
R7: 10k; C_0603_1608Metric; LCSC C22369937
R63: 4.7k; C_0603_1608Metric
R64, R69, R70: 1.5k; R_0603_1608Metric_Pad0.98x0.95mm_HandSolder
R66: 100k; C_0603_1608Metric
R68: 32k; R_0603_1608Metric
R71, R72, R74, R76: 680; R_0603_1608Metric_Pad0.98x0.95mm_HandSolder; LCSC C22356475
R73: 0; R_0402_1005Metric; not fitted
R75, R78: 10k; R_0603_1608Metric; LCSC C22369937
R77: 1k; R_0603_1608Metric; LCSC C22356624
TP1, TP2, TP3, TP4: TestPoint; TestPoint_Pad_D2.0mm
U1: INA3221; Texas_RGV0016A_VQFN-16-1EP_4x4mm_P0.65mm_EP2.1x2.1mm; LCSC C181255
U6, U9: TPS2116DRL; SOT-583-8; LCSC C3235557
U10, U12: TPSM33620-Q1; RDN0011A-MFG; LCSC C49261907
U11: TPSM33620-Q1; RDN0011A-MFG; LCSC C51956999

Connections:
3V3: C1.1, C2.2, C15.1, C60.1, R2.2, R4.1, R8.1, R9.1, R71.2, R75.2, R133.1, R134.1, TP3.1, U1.1 (IN-3), U1.4 (VS); also elsewhere on the board
3V3_Bat: C74.1, C75.1, C77.1, U6.6 (VIN2), U10.4 (VOUT), U10.9 (FB)
3V3_USB: C58.1, C76.1, C78.1, R65.2, U6.3 (VIN1), U6.5 (MODE), U12.4 (VOUT), U12.9 (FB)
5V: C6.1, C85.1, R7.2, R64.2, R162.2, TP2.1, U1.14 (IN-2); also elsewhere on the board
5V_Bat: C8.1, C56.1, C61.1, R69.2, U9.6 (VIN2), U11.4 (VOUT), U11.9 (FB)
5V_USB: C4.1, C9.1, C55.1, C115.1, R5.2, R70.2, U9.3 (VIN1), U9.5 (MODE), U12.2 (EN), U12.3 (VIN); also elsewhere on the board
12.8V: C3.1, C5.1, C32.1, C71.1, C79.1, C84.1, C116.1, C117.1, R3.2, R63.2, R78.2, TP1.1, U1.11 (IN-1), U10.2 (EN), U10.3 (VIN), U11.2 (EN), U11.3 (VIN); also elsewhere on the board
12.8V_BAT: C38.1, D16.1 (A1), F1.2, IC1.3 (IN_1), IC1.4 (IN_2), R67.1, R73.1
/Alimentation/EFUSE_FLT: IC1.6 (~FLT), R78.1
/Alimentation/LED1: R72.2; also elsewhere on the board
/Alimentation/LED2: R74.2; also elsewhere on the board
/Alimentation/LED3: R76.2; also elsewhere on the board
/Alimentation/PM_CRIT: R133.2, U1.9 (CRITICAL); also elsewhere on the board
/Alimentation/PM_SCL: R9.2, U1.6 (SCL); also elsewhere on the board
/Alimentation/PM_SDA: R8.2, U1.7 (SDA); also elsewhere on the board
/Alimentation/PM_TC: R4.2, U1.13 (TC); also elsewhere on the board
/Alimentation/PM_WARN: R134.2, U1.8 (WARNING); also elsewhere on the board
/Alimentation/Psense1_IN+: IC1.5 (OUT), R3.1, R73.2, U1.12 (IN+1)
/Alimentation/Psense2_IN+: R162.1, U1.15 (IN+2), U9.2 (VOUT), U9.7 (VOUT)
/Alimentation/Psense3_IN+: R2.1, U1.2 (IN+3), U6.2 (VOUT), U6.7 (VOUT)
GND: C1.2, C2.1, C3.2, C4.2, C5.2, C6.2, C8.2, C9.2, C15.2, C32.2, C38.2, C55.2, C56.2, C57.2, C58.2, C59.2, C60.2, C61.2, C62.2, C64.2, C71.2, C74.2, C75.2, C76.2, C77.2, C78.2, C79.2, C84.2, C85.2, C107.2, C112.2, C115.2, C116.2, C117.2, D7.1 (K), D8.1 (K), D9.1 (K), D10.1 (K), D11.1 (K), D12.1 (K), D13.1 (K), D14.1 (K), D16.2 (A2), IC1.8 (GND_1), IC1.9 (GND_2), J19.1, R6.1, R66.1, R68.2, R77.2, TP4.1, U1.3 (GND), U1.5 (A0), U1.17 (EP), U6.1 (GND), U9.1 (GND), U10.10 (GND), U10.11 (MODE/SYNC), U11.10 (GND), U11.11 (MODE/SYNC), U12.10 (GND), U12.11 (MODE/SYNC); also elsewhere on the board
unnamed: D7.2 (A), R63.1
unnamed: D8.2 (A), R64.1
unnamed: D9.2 (A), R69.1
unnamed: D10.2 (A), R70.1
unnamed: D11.2 (A), R71.1
unnamed: D12.2 (A), R72.1
unnamed: D13.2 (A), R74.1
unnamed: D14.2 (A), R76.1
unnamed: C64.1, IC1.1 (DVDT)
unnamed: IC1.7 (ILM), R77.1
unnamed: IC1.2 (~EN/OVLO), R67.2, R68.1
unnamed: R132.2, U1.10 (PV)
unnamed: R132.1, U1.16 (VPU)
unnamed: R65.1, R66.2, U6.4 (PR1)
unnamed: R75.1, U6.8 (ST)
unnamed: R5.1, R6.2, U9.4 (PR1)
unnamed: R7.1, U9.8 (ST)
unnamed: C62.1, U10.8 (VCC)
unnamed: C107.1, U11.8 (VCC)
unnamed: C112.1, U12.8 (VCC)
VIN: C57.1, C59.1, F1.1, J19.2

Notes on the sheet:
5V USB -> 3.3V USB
1.7A max
12.8V -> 3.3V
3V3 Bus
Capacitor -25V -X7R
12.8V -> 5V
Calcul des compos
EFuse
5V Bus
Batt
Monitor
LED

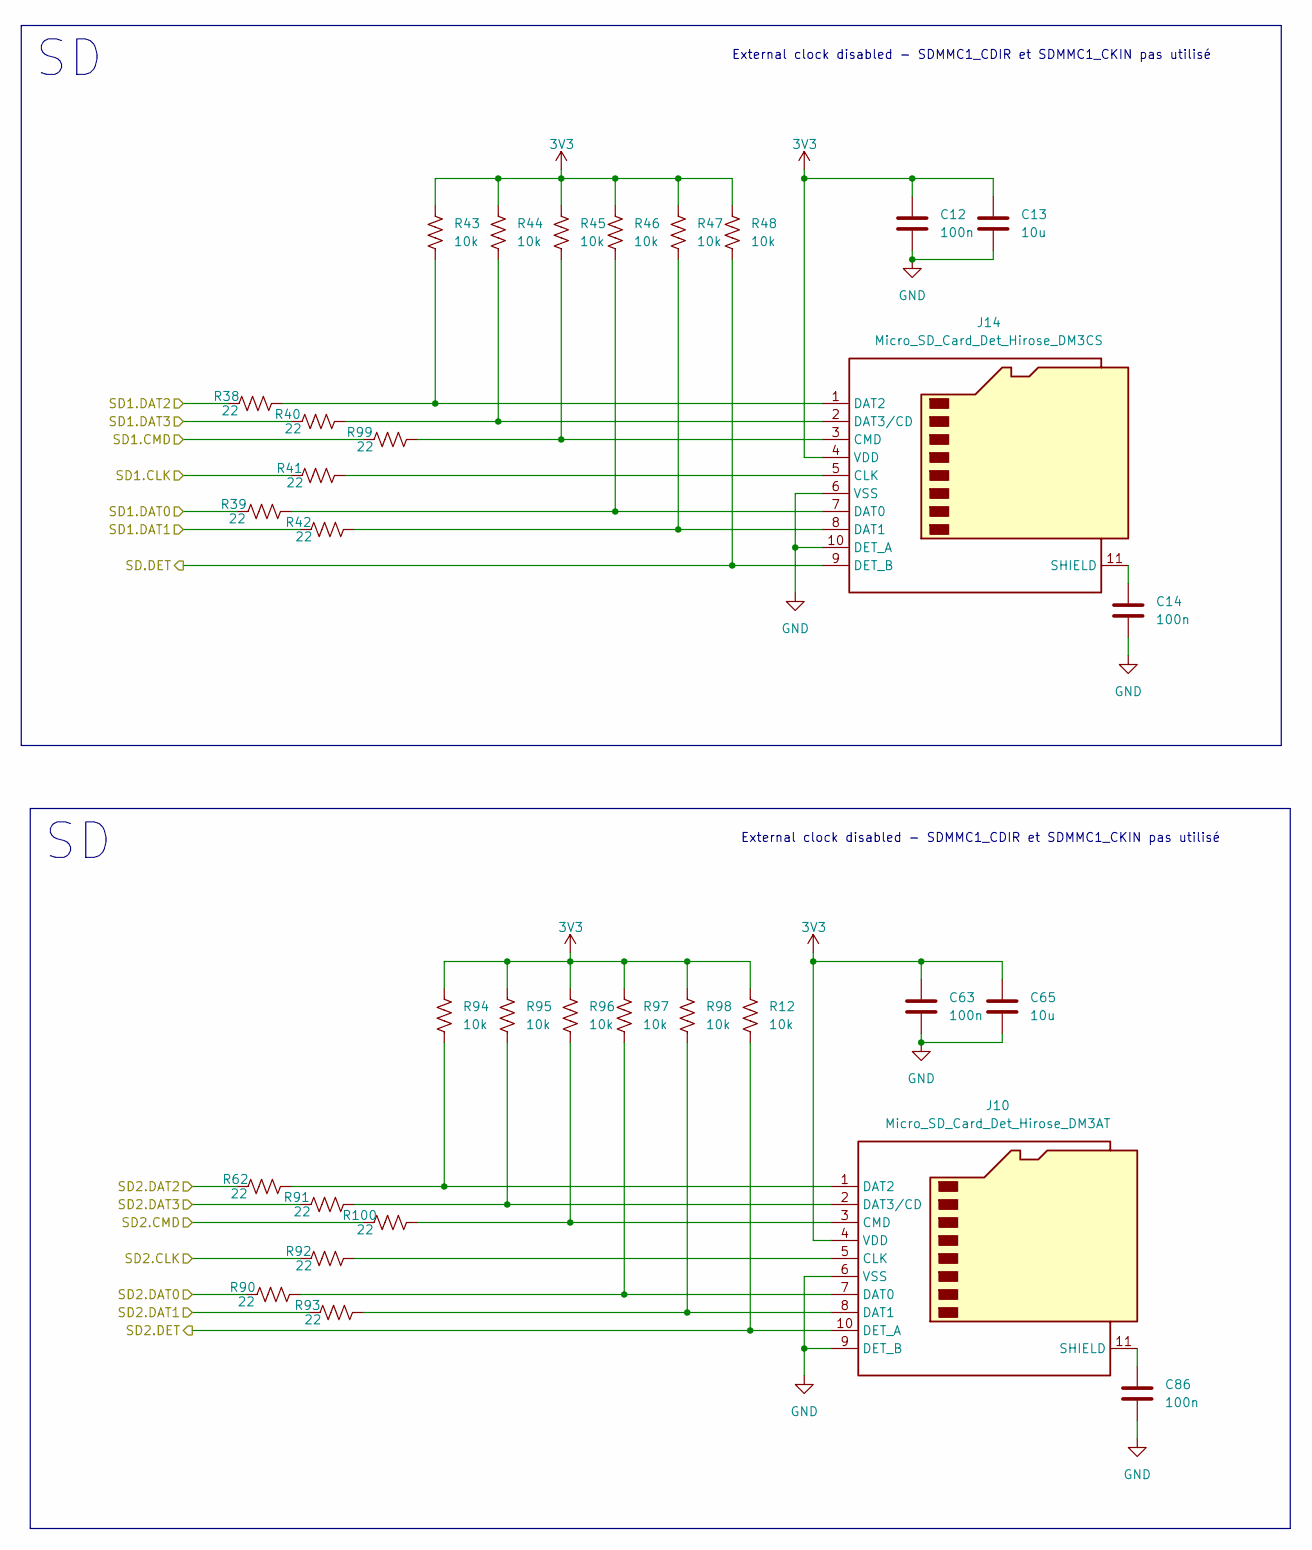
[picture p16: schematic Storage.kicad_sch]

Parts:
C12, C14, C63, C86: 100n; C_0603_1608Metric; LCSC C14663
C13, C65: 10u; C_0603_1608Metric; LCSC C22399626
J10: Micro_SD_Card_Det_Hirose_DM3AT; microSD_HC_Hirose_DM3AT-SF-PEJM5; LCSC C114218
J14: Micro_SD_Card_Det_Hirose_DM3CS; HRS_DM3CS-SF; LCSC C202111
R12, R43, R44, R45, R46, R47, R48, R94, R95, R96, R97, R98: 10k; R_0402_1005Metric; LCSC C173683
R38, R39, R40, R41, R42, R62, R90, R91, R92, R93, R99, R100: 22; R_0402_1005Metric; LCSC C25092

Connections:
3V3: C12.1, C13.1, C63.1, C65.1, J10.4 (VDD), J14.4 (VDD), R12.1, R43.1, R44.1, R45.1, R46.1, R47.1, R48.1, R94.1, R95.1, R96.1, R97.1, R98.1; also elsewhere on the board
/MCU/SD1.CLK: R41.1; also elsewhere on the board
/MCU/SD1.CMD: R99.1; also elsewhere on the board
/MCU/SD1.DAT0: R39.1; also elsewhere on the board
/MCU/SD1.DAT1: R42.1; also elsewhere on the board
/MCU/SD1.DAT2: R38.1; also elsewhere on the board
/MCU/SD1.DAT3: R40.1; also elsewhere on the board
/MCU/SD2.CLK: R92.1; also elsewhere on the board
/MCU/SD2.CMD: R100.1; also elsewhere on the board
/MCU/SD2.DAT0: R90.1; also elsewhere on the board
/MCU/SD2.DAT1: R93.1; also elsewhere on the board
/MCU/SD2.DAT2: R62.1; also elsewhere on the board
/MCU/SD2.DAT3: R91.1; also elsewhere on the board
/MCU/SD2.DET: J10.10 (DET_A), R12.2; also elsewhere on the board
/MCU/SD.DET: J14.9 (DET_B), R48.2; also elsewhere on the board
GND: C12.2, C13.2, C14.2, C63.2, C65.2, C86.2, J10.6 (VSS), J10.9 (DET_B), J14.6 (VSS), J14.10 (DET_A); also elsewhere on the board
unnamed: J10.5 (CLK), R92.2
unnamed: J10.3 (CMD), R96.2, R100.2
unnamed: J10.7 (DAT0), R90.2, R97.2
unnamed: J10.8 (DAT1), R93.2, R98.2
unnamed: J10.1 (DAT2), R62.2, R94.2
unnamed: J10.2 (DAT3/CD), R91.2, R95.2
unnamed: C86.1, J10.11 (SHIELD)
unnamed: J14.5 (CLK), R41.2
unnamed: J14.3 (CMD), R45.2, R99.2
unnamed: J14.7 (DAT0), R39.2, R46.2
unnamed: J14.8 (DAT1), R42.2, R47.2
unnamed: J14.1 (DAT2), R38.2, R43.2
unnamed: J14.2 (DAT3/CD), R40.2, R44.2
unnamed: C14.1, J14.11 (SHIELD)

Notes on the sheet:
External clock disabled - SDMMC1_CDIR et SDMMC1_CKIN pas utilisé

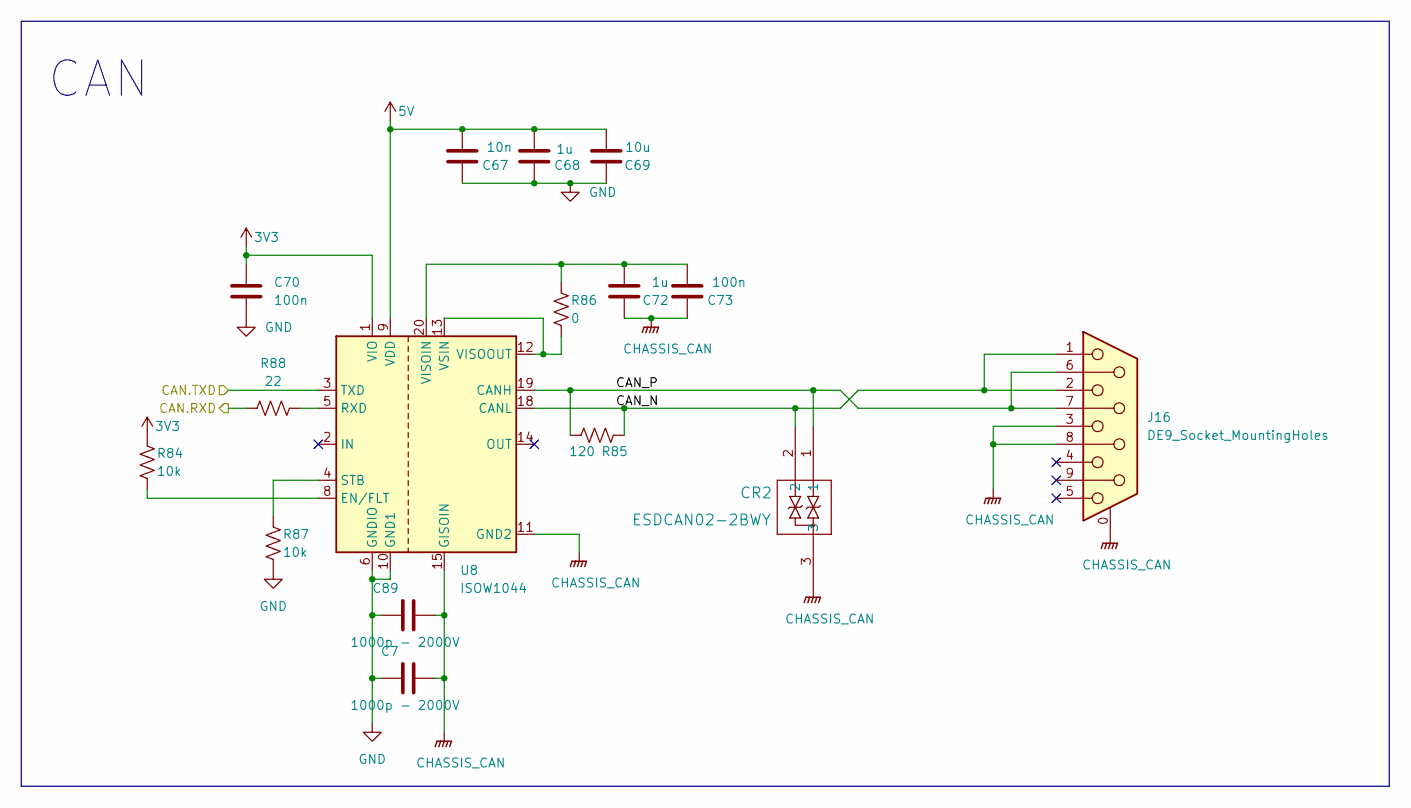
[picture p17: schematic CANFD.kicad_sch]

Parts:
C7, C89: 1000p - 2000V; C_1210_3225Metric; LCSC C9196
C67: 10n; C_0603_1608Metric; LCSC C100042
C68, C72: 1u; C_0603_1608Metric; LCSC C59302
C69: 10u; C_0603_1608Metric; LCSC C22399626
C70, C73: 100n; C_0603_1608Metric; LCSC C14663
CR2: ESDCAN02-2BWY; SOT323-3L_STM; LCSC C2969759
J16: DE9_Socket_MountingHoles; DSUB-9_Socket_Vertical_P2.77x2.84mm_MountingHoles; LCSC C141882
R84, R87: 10k; R_0603_1608Metric; LCSC C22369937
R85: 120; R_0603_1608Metric_Pad0.98x0.95mm_HandSolder; LCSC C177328
R86: 0; R_0402_1005Metric; LCSC C17168
R88: 22; R_0402_1005Metric; LCSC C25092
U8: ISOW1044; SOIC-20W_7.5x12.8mm_P1.27mm; LCSC C3234830

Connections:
3V3: C70.1, R84.1, U8.1 (VIO); also elsewhere on the board
5V: C67.2, C68.2, C69.2, U8.9 (VDD); also elsewhere on the board
/CAN FD/CAN.RXD: R88.1; also elsewhere on the board
/CAN FD/CAN.TXD: U8.3 (TXD); also elsewhere on the board
/CAN FD/CAN_N: CR2.2, J16.1, J16.2, R85.1, U8.18 (CANL)
/CAN FD/CAN_P: CR2.1, J16.6, J16.7, R85.2, U8.19 (CANH)
CHASSIS_CAN: C7.2, C72.1, C73.1, C89.2, CR2.3, J16.0 (PAD), J16.3, J16.8, U8.11 (GND2), U8.15 (GISOIN), U8.16 (GISOIN), U8.17 (GISOIN)
GND: C7.1, C67.1, C68.1, C69.1, C70.2, C89.1, R87.2, U8.6 (GNDIO), U8.10 (GND1); also elsewhere on the board
unnamed: R84.2, U8.8 (EN/FLT)
unnamed: R88.2, U8.5 (RXD)
unnamed: R87.1, U8.4 (STB)
unnamed: C72.2, C73.2, R86.1, U8.20 (VISOIN)
unnamed: R86.2, U8.12 (VISOOUT), U8.13 (VSIN)

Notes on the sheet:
CAN

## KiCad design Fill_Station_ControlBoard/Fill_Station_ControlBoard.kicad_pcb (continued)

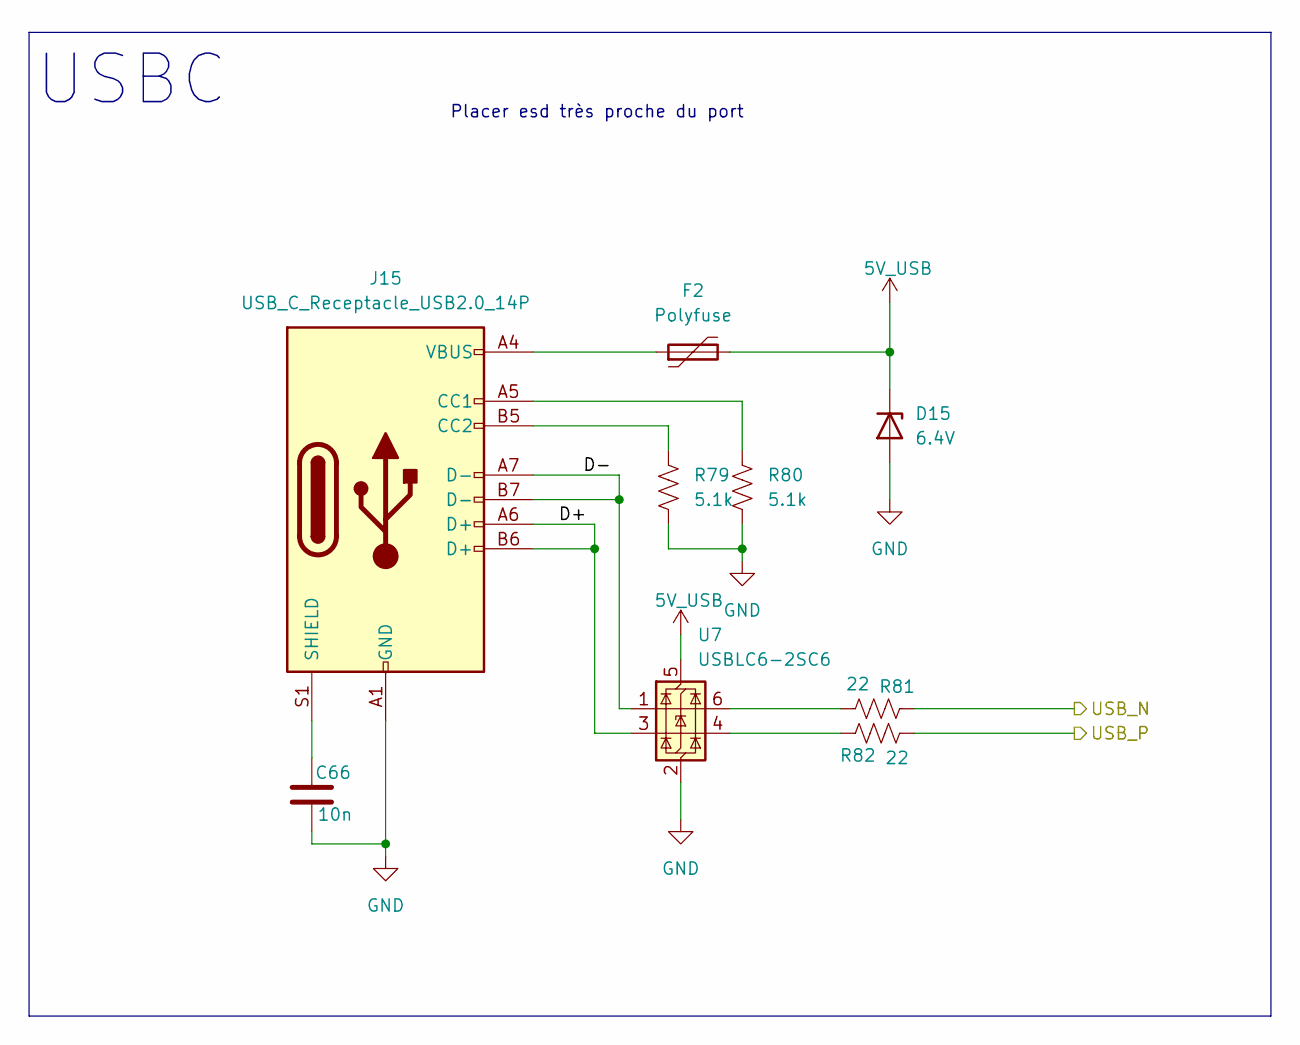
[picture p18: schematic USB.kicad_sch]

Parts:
C66: 10n; C_0603_1608Metric; LCSC C100042
D15: 6.4V; D_SOD-123; LCSC C79598
F2: Polyfuse; Fuse_1206_3216Metric; LCSC C70083
J15: USB_C_Receptacle_USB2.0_14P; USB_C_Receptacle_GCT_USB4105-xx-A_16P_TopMnt_Horizontal; LCSC C393939
R79, R80: 5.1k; R_0402_1005Metric; LCSC C25905
R81, R82: 22; R_0402_1005Metric; LCSC C25092
U7: USBLC6-2SC6; SOT-23-6; LCSC C7519

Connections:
5V_USB: D15.1 (K), F2.2, U7.5 (VBUS); also elsewhere on the board
/MCU/USBC.DM: R81.1; also elsewhere on the board
/MCU/USBC.DP: R82.2; also elsewhere on the board
/USB/D+: J15.A6 (D+), J15.B6 (D+), U7.3 (I/O2)
/USB/D-: J15.A7 (D-), J15.B7 (D-), U7.1 (I/O1)
GND: C66.2, D15.2 (A), J15.A1 (GND), J15.A12 (GND), J15.B1 (GND), J15.B12 (GND), R79.2, R80.2, U7.2 (GND); also elsewhere on the board
unnamed: F2.1, J15.A4 (VBUS), J15.A9 (VBUS), J15.B4 (VBUS), J15.B9 (VBUS)
unnamed: J15.A5 (CC1), R80.1
unnamed: J15.B5 (CC2), R79.1
unnamed: C66.1, J15.S1 (SHIELD)
unnamed: R81.2, U7.6 (I/O1)
unnamed: R82.1, U7.4 (I/O2)

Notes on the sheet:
Placer esd très proche du port
USBC

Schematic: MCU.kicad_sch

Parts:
BT1: RTC_BAT; Battery_Panasonic_CR2032-HFN_Horizontal_CircularHoles; Manufacturer Part Number BHX1-1025-SM; LCSC C910763
C16, C23, C25, C26, C27, C28, C29, C30, C31, C33, C34, C35, C36, C37, C39, C40, C41, C42, C43, C44, C46, C48, C83, C90, C91: 100n; C_0402_1005Metric; LCSC C60474
C17, C18, C19, C21: 2.2u; C_0603_1608Metric
C20: 100n; C_0603_1608Metric; LCSC C14663
C22, C45, C47, C50, C53: 1u; C_0603_1608Metric; LCSC C59302
C24, C54: 4.7u; C_0603_1608Metric; LCSC C108342
C49, C52, C87: 10u; C_0603_1608Metric; LCSC C22399626
C51: *; C_0402_1005Metric; not fitted
C88: 100u; C_0805_2012Metric; LCSC C141660
FID1, FID2, FID3: Fiducial; Fiducial_0.5mm_Mask1mm
H1, H2, H3, H4: M3_Hole_With_Spacer_H10mm; MountingHole_3.2mm_With_Spacer_H10mm
J12: Conn_02x05_Counter_Clockwise; PinSocket_2x05_P2.00mm_Vertical
L2: L_Ferrite; R_0402_1005Metric; LCSC C160977
R49, R50: 10k; R_0603_1608Metric
R51, R53: 10k; R_0402_1005Metric; LCSC C173683
R52: 10k; C_0402_1005Metric; LCSC C173683
R54: 0; R_0402_1005Metric; LCSC C17168
R89, R103, R113, R114: 22; R_0402_1005Metric; LCSC C25092
SW1: RESET; SW_DPDT_CK_JS202011JCQN; LCSC C221666
SW2: BOOT; SW_DPDT_CK_JS202011JCQN; LCSC C221666
U2: STM32H747IITx; LQFP-176_24x24mm_P0.5mm; LCSC C730199
Y1: ASV-25.000MHz; Oscillator_SMD_Abracon_ASV-4Pin_7.0x5.1mm; LCSC C1987509
Y2: ASV-32.768kHz; Oscillator_SMD_Abracon_ASV-4Pin_7.0x5.1mm; LCSC C17591433

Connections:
3V3: C24.1, C25.1, C26.1, C27.1, C28.1, C29.1, C30.1, C31.1, C33.1, C34.1, C35.1, C36.1, C37.1, C39.1, C40.1, C41.1, C42.1, C43.1, C44.1, C45.1, C46.1, C47.1, C48.1, C49.1, C50.1, C52.1, C53.1, C54.1, C87.1, C88.1, J12.1, L2.2, R51.1, R52.1, R53.1, SW1.3 (C), SW2.3 (C), U2.7 (VDD), U2.13 (VDD), U2.16 (VDDSMPS), U2.25 (VDD), U2.44 (VDD), U2.48 (VDD), U2.65 (VDD), U2.71 (VDD), U2.82 (VDDLDO), U2.84 (VDD), U2.92 (VDD), U2.99 (VDD), U2.113 (VDD), U2.121 (VDD33_USB), U2.126 (VDD), U2.135 (VDDLDO), U2.136 (VDD), U2.152 (VDD), U2.160 (VDD), U2.175 (VDDLDO), U2.176 (VDD), Y1.4 (Vdd), Y2.4 (Vdd); also elsewhere on the board
3V3A: C16.1, C83.1, L2.1, U2.39 (VREF+), U2.40 (VDDA)
5V: C22.1, C23.1, U2.120 (VDD50_USB); also elsewhere on the board
/Alimentation/LED1: U2.19 (PF1); also elsewhere on the board
/Alimentation/LED2: U2.20 (PF2); also elsewhere on the board
/Alimentation/LED3: U2.21 (PF3); also elsewhere on the board
/Alimentation/PM_CRIT: U2.59 (PF12); also elsewhere on the board
/Alimentation/PM_SCL: U2.61 (PF14); also elsewhere on the board
/Alimentation/PM_SDA: U2.62 (PF15); also elsewhere on the board
/Alimentation/PM_TC: U2.63 (PG0); also elsewhere on the board
/Alimentation/PM_WARN: U2.60 (PF13); also elsewhere on the board
/CAN FD/CAN.RXD: U2.168 (PB8); also elsewhere on the board
/CAN FD/CAN.TXD: R89.2; also elsewhere on the board
/Control/BUZZ: U2.91 (PD10); also elsewhere on the board
/Control/E-match1: U2.95 (PD12); also elsewhere on the board
/Control/E-match1_Cont: U2.89 (PD8); also elsewhere on the board
/Control/E-match1_Det: U2.96 (PD13); also elsewhere on the board
/Control/E-match2: U2.97 (PD14); also elsewhere on the board
/Control/E-match2_Cont: U2.90 (PD9); also elsewhere on the board
/Control/E-match2_Det: U2.98 (PD15); also elsewhere on the board
/Control/GPIO1: U2.1 (PE2); also elsewhere on the board
/Control/GPIO2: U2.2 (PE3); also elsewhere on the board
/Control/GPIO3: U2.3 (PE4); also elsewhere on the board
/Control/GPIO4: U2.4 (PE5); also elsewhere on the board
/Control/GPIO5: U2.5 (PE6); also elsewhere on the board
/Control/Servo.Signal1: U2.69 (PE9); also elsewhere on the board
/Control/Servo.Signal2: U2.68 (PE8); also elsewhere on the board
/Control/Servo.Signal3: U2.67 (PE7); also elsewhere on the board
/Ethernet/Eth.CRS_DV: U2.52 (PA7); also elsewhere on the board
/Ethernet/Eth.MDC: U2.35 (PC1); also elsewhere on the board
/Ethernet/Eth.MDIO: U2.43 (PA2); also elsewhere on the board
/Ethernet/Eth.REFCLKO: U2.42 (PA1); also elsewhere on the board
/Ethernet/Eth.RST: U2.51 (PA6); also elsewhere on the board
/Ethernet/Eth.RXD_N: U2.54 (PC5); also elsewhere on the board
/Ethernet/Eth.RXD_P: U2.53 (PC4); also elsewhere on the board
/Ethernet/Eth.TXD_N: R114.2; also elsewhere on the board
/Ethernet/Eth.TXD_P: R113.2; also elsewhere on the board
/Ethernet/Eth.TXEN: R103.2; also elsewhere on the board
/MCU/Boot: R50.2, U2.167 (BOOT0)
/MCU/Clock_25Mhz: C51.1, R54.2, U2.31 (PH0)
/MCU/Clock_32.768khz: U2.10 (PC14), Y2.3 (OUT)
/MCU/I2C1.SCL: U2.165 (PB6); also elsewhere on the board
/MCU/I2C1.SDA: U2.166 (PB7); also elsewhere on the board
/MCU/IO: J12.4, U2.144 (PD1)
/MCU/NRST: J12.6, R49.2, U2.33 (NRST)
/MCU/SD1.CLK: U2.142 (PC12); also elsewhere on the board
/MCU/SD1.CMD: U2.145 (PD2); also elsewhere on the board
/MCU/SD1.DAT0: U2.124 (PC8); also elsewhere on the board
/MCU/SD1.DAT1: U2.125 (PC9); also elsewhere on the board
/MCU/SD1.DAT2: U2.140 (PC10); also elsewhere on the board
/MCU/SD1.DAT3: U2.141 (PC11); also elsewhere on the board
/MCU/SD2.CLK: U2.149 (PD6); also elsewhere on the board
/MCU/SD2.CMD: U2.150 (PD7); also elsewhere on the board
/MCU/SD2.DAT0: U2.87 (PB14); also elsewhere on the board
/MCU/SD2.DAT1: U2.88 (PB15); also elsewhere on the board
/MCU/SD2.DAT2: U2.162 (PB3); also elsewhere on the board
/MCU/SD2.DAT3: U2.163 (PB4); also elsewhere on the board
/MCU/SD2.DET: U2.147 (PD4); also elsewhere on the board
/MCU/SD.DET: U2.116 (PG6); also elsewhere on the board
/MCU/SPI4.CS: U2.77 (PE15); also elsewhere on the board
/MCU/SPI4.MISO: U2.75 (PE13); also elsewhere on the board
/MCU/SPI4.MOSI: U2.76 (PE14); also elsewhere on the board
/MCU/SPI4.SCK: U2.74 (PE12); also elsewhere on the board
/MCU/SPI5.CS: U2.155 (PG11); also elsewhere on the board
/MCU/SPI5.MISO: U2.156 (PG12); also elsewhere on the board
/MCU/SPI5.MOSI: U2.158 (PG14); also elsewhere on the board
/MCU/SPI5.SCK: U2.157 (PG13); also elsewhere on the board
/MCU/SWCLK: J12.9, U2.138 (PA14)
/MCU/SWDIO: J12.10, U2.132 (PA13)
/MCU/USBC.DM: U2.130 (PA11); also elsewhere on the board
/MCU/USBC.DP: U2.131 (PA12); also elsewhere on the board
GND: BT1.2 (-), C16.2, C17.2, C18.2, C19.2, C20.2, C21.2, C22.2, C23.2, C24.2, C25.2, C26.2, C27.2, C28.2, C29.2, C30.2, C31.2, C33.2, C34.2, C35.2, C36.2, C37.2, C39.2, C40.2, C41.2, C42.2, C43.2, C44.2, C45.2, C46.2, C47.2, C48.2, C49.2, C50.2, C51.2, C52.2, C53.2, C54.2, C83.2, C87.2, C88.2, C90.2, C91.2, H1.1, H2.1, H3.1, H4.1, J12.2, J12.3, J12.5, SW1.1 (A), SW2.1 (A), U2.6 (VSS), U2.12 (VSS), U2.14 (VSSSMPS), U2.24 (VSS), U2.38 (VSSA), U2.45 (VSS), U2.47 (VSS), U2.64 (VSS), U2.70 (VSS), U2.81 (VSS), U2.83 (VSS), U2.93 (VSS), U2.100 (VSS), U2.103 (DSI_D0P), U2.104 (DSI_D0N), U2.105 (VSSDSI), U2.106 (DSI_CKP), U2.107 (DSI_CKN), U2.109 (VSSDSI), U2.112 (VSS), U2.119 (VSS), U2.134 (VSS), U2.137 (VSS), U2.151 (VSS), U2.159 (VSS), U2.173 (VSS), Y1.2 (GND), Y2.2 (GND); also elsewhere on the board
unnamed: C17.1, U2.80 (VCAP)
unnamed: C18.1, U2.133 (VCAP)
unnamed: C19.1, U2.172 (VCAP)
unnamed: C91.1, R49.1, SW1.2 (B)
unnamed: C90.1, R50.1, SW2.2 (B)
unnamed: R89.1, U2.169 (PB9)
unnamed: R103.1, U2.79 (PB11)
unnamed: R113.1, U2.85 (PB12)
unnamed: R114.1, U2.86 (PB13)
unnamed: R51.2, U2.174 (PDR_ON)
unnamed: BT1.1 (+), C20.1, U2.8 (VBAT)
unnamed: C21.1, U2.101 (VCAPDSI)
unnamed: R52.2, Y1.1 (EN)
unnamed: R54.1, Y1.3 (OUT)
unnamed: R53.2, Y2.1 (EN)

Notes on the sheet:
Solder
BOOT
EXTERNAL OSCILLATOR
RESET
SWD
Mechanical
DECOUPLING MCU
Microchip Pinout
Plastic stand-off

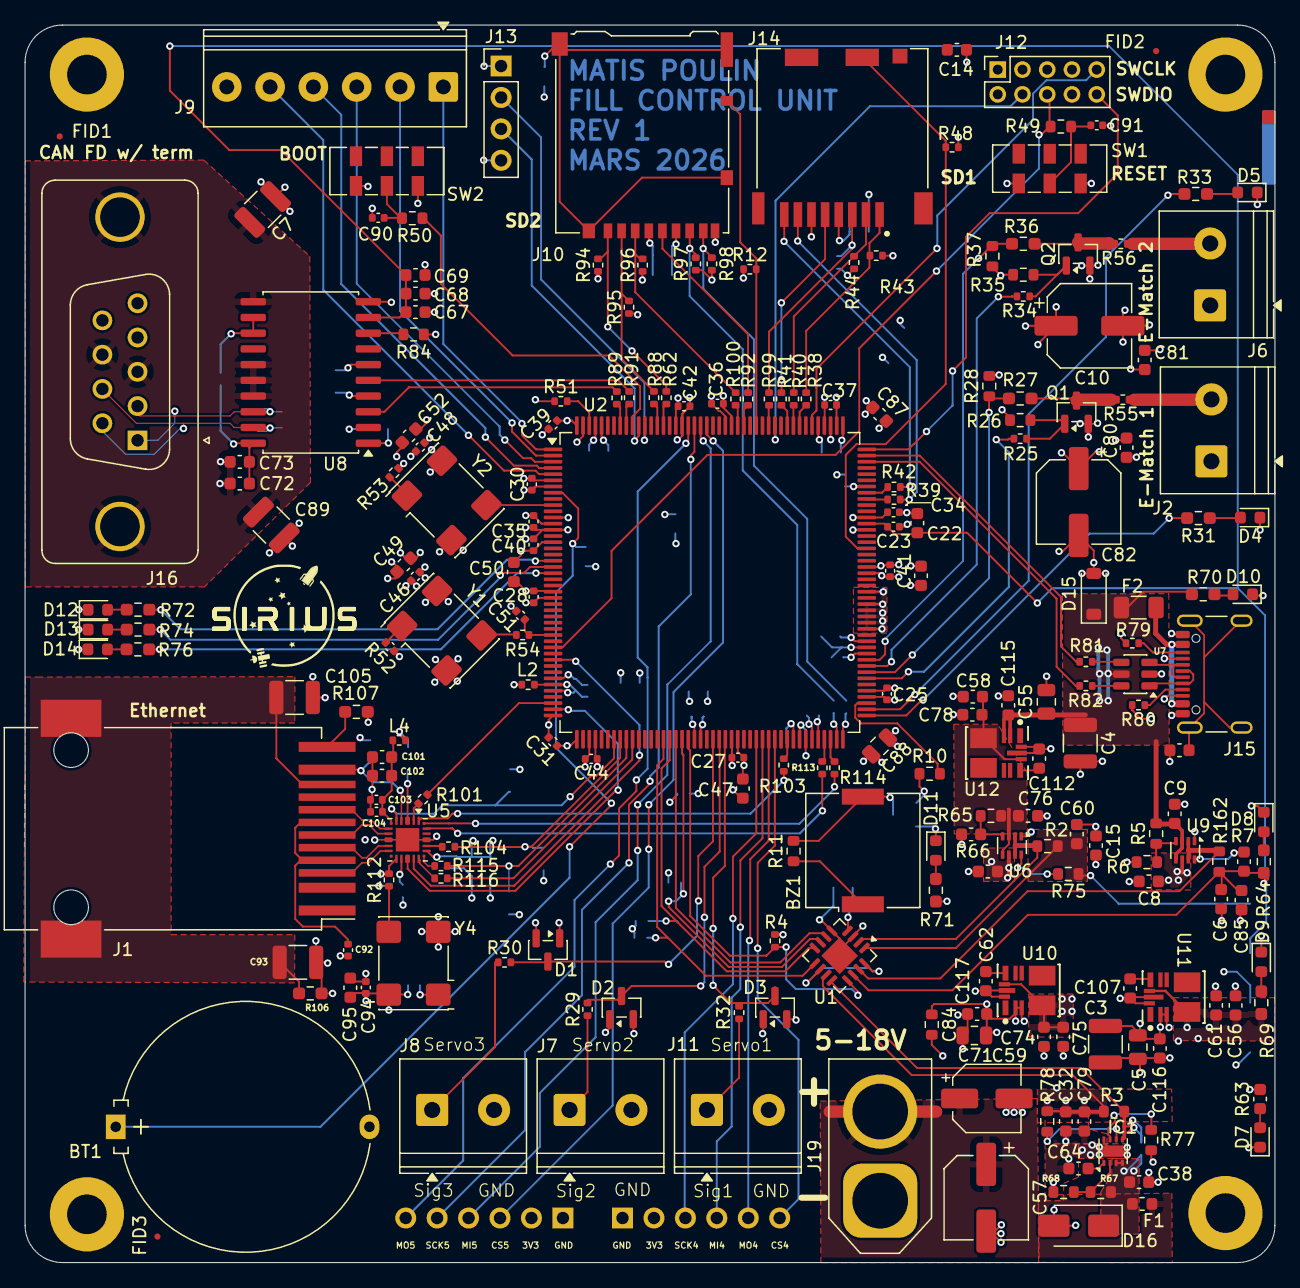
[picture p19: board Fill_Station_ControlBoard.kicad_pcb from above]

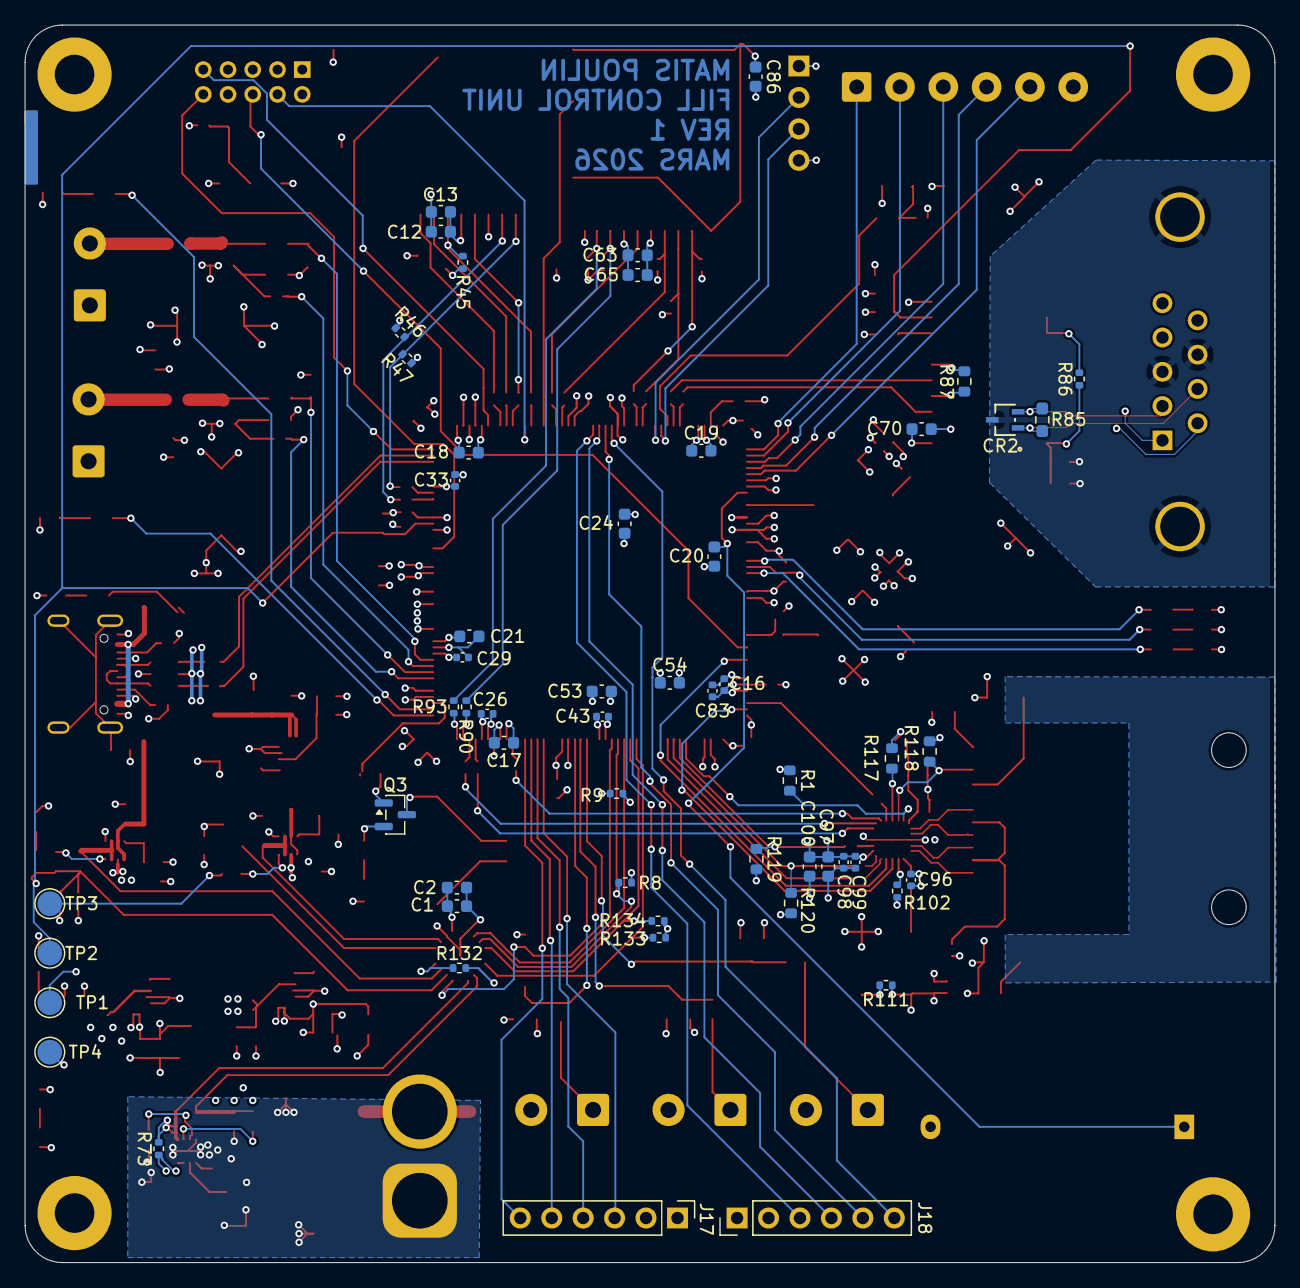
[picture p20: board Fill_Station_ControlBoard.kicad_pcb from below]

Board: 6 copper layers, 101.0 x 100.0 mm, 279 parts (56 on the bottom side), 179 nets.

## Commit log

2025-12-02 First upload
    Juste avoir des fichier
    [Fill_Station_ControlBoard.kicad_pcb, Fill_Station_ControlBoard.kicad_sch]
2025-12-09 1282025PostRéu
    [Fill_Station_ControlBoard.kicad_sch]
2025-12-09 2025/12/08 - Sch Ethernet
    [Fill_Station_ControlBoard.kicad_sch]
2026-01-24 Restructure + phy ethernet
    Finaliser le phy ethernet et changé pour hyerarchical sheets
    [Connecteurs.kicad_sch, Fill_Station_ControlBoard.kicad_sch, Storage.kicad_sch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]
2026-01-24 petites modifs pour ethernet + usb
    [Connecteurs.kicad_sch, Fill_Station_ControlBoard.kicad_sch, Storage.kicad_sch]
2026-01-26 Développer plus le circuit CAN
    [Connecteurs.kicad_sch]
2026-02-09 Ajouter schema de JTAG
    [Connecteurs.kicad_sch, Fill_Station_ControlBoard.kicad_sch, Storage.kicad_sch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]
2026-02-15 Changement de CAN et quelques trucs
    [Connecteurs.kicad_sch, Fill_Station_ControlBoard.kicad_sch, Heaters.kicad_sch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]
2026-02-15 Assignation footprint pis valeurs resistances del
    [Connecteurs.kicad_sch, Fill_Station_ControlBoard.kicad_pcb, Fill_Station_ControlBoard.kicad_sch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]
2026-02-17 Fait des trucs (commencer arrangement de pièces sur PCB
    [Connecteurs.kicad_sch, Fill_Station_ControlBoard.kicad_pcb, Fill_Station_ControlBoard.kicad_sch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]
2026-02-18 Modifs de l'organisation des pages
    [Alimentation.kicad_sch, CANFD.kicad_sch, Connecteurs.kicad_sch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]
2026-02-18 début layout
    [Fill_Station_ControlBoard.kicad_pcb, Fill_Station_ControlBoard.kicad_sch, MCU.kicad_sch]
2026-02-21 Ajout power
    [Alimentation.kicad_sch, CANFD.kicad_sch, Connecteurs.kicad_sch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]
2026-02-21 Ajout de footprint
    [Storage.kicad_sch, USB.kicad_sch]
2026-02-21 Changement val Resistance a 10k
    [Connecteurs.kicad_sch]
2026-02-23 wiring de certaines parties du PCB et placement de quelques composantes sur le PCB
    [Fill_Station_ControlBoard.kicad_pcb, MCU.kicad_sch]
2026-02-24 Petits changements et truc que j'ai fait lundi
    [Fill_Station_ControlBoard.kicad_pcb]
2026-02-26 PCB fait
    [Alimentation.kicad_sch, CANFD.kicad_sch, Connecteurs.kicad_sch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]
2026-03-03 Travail Layout
    [Alimentation.kicad_sch, CANFD.kicad_sch, Connecteurs.kicad_sch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]
2026-03-04 PCB presque terminé
    Modifs de l'alim
    [Alimentation.kicad_sch, CANFD.kicad_sch, Connecteurs.kicad_sch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]
2026-03-07 finalisé le pcb
    [Alimentation.kicad_sch, Fill_Station_ControlBoard.kicad_pcb, Fill_Station_ControlBoard.kicad_sch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]
2026-03-17 PCB fini avant review avec greg
    [Alimentation.kicad_sch, Fill_Station_ControlBoard.kicad_pcb, Fill_Station_ControlBoard.kicad_sch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]
